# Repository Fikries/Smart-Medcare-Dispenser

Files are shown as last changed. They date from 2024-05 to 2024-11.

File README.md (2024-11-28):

## Project Name
PERSONAL MEDICINE DISPENSER WITH NOTIFICATION FOR ELDERLY CARE IN NURSING HOME USING ESP32 INTERGRATED WITH MYSQL DATABASE

## Component
- 1.Esp32 Devkit v1
- 2.push buttuon
- 3.Led
- 4.Stepper motor 28-byj
- 5.Uln2003
- 6.adapter 12V
- 7.LCD 16 X 2
- 8.BUZZER

## HOW TO SET UP MY PROJECT
- 1.Pull all the code to Vs code
- 2.download Xampp
- 3.make sure on xampp,press start apache
- 4.press admin on xampp control panel
- 5.build one table name and and import table MYSQL from the github
- 6.press admin on apache at xampp control panel
- 7.make sure directary like this "http://localhost/fikrifyp/login.php" it depend on what you save code folder on your laptop
- 
- 8.Because of this project rely on changes of ip address because of using hotspot phone, there are 2 way to find it and one from serial monitor arduiono ide and one from phone
- WhatsApp Image 2024-11-26 at 21 02 38_f4ae71a4
- WhatsApp Image 2024-11-26 at 21 02 38_19f7a604
- 9.After you got ip address, make sure change the ip address on interface.php and spinworker.php

## how to set up PHPMAILER
- 1.OPEN GOOGLE ACC
- 2.PRESS MANAGE ACC
- 3.SEARCH APP PASWORD
- 4.CONFIGURE UNTUILL YOU GET THE CODE THEN PASTE IT INTO THE CODING
- 
- 5.paste it into mail password
- 

- whoever want detail of my fyp can contact me through 0182671172

## Project picture
- WhatsApp Image 2024-10-29 at 00 03 51_c078c0ca

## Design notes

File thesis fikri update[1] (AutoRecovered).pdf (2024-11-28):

## SMART MEDCARE DISPENSER: PERSONAL

## MEDICINE DISPENSER WITH NOTIFICATION

## FOR ELDERLY CARE IN NURSING

## HOME USING ESP32 INTEGRATED

## WITH MYSQL DATABASE

MUHAMMAD FIKRI BIN ZAHARUDIN

MARA JAPAN INDUSTRIAL INSTITUTE

DECLARATION OF THESIS /PROJECT REPORT AND COPYRIGHT

Author’s full name | Date of Birth
MUHAMMAD FIKRI BIN ZAHARUDIN | 26 FEBRUARY 2002
Title | : SMART MEDCARE DISPENSER: PERSONAL MEDICINE DISPENSER WITH
NOTIFICATION FOR ELDERLY CARE IN NURSING HOME USING ESP32 INTERGRATED WITH MYSQL DATABASE

Academic Session : 2022 -2024

I declare that this project report is classified as:

CONFIDENTIAL (Contains confidential information under the Official Secret Act 1972)*

RESTRICTED | (Contains restricted information as specified by the
organization where research was done)*

✓

OPEN ACCESS I agree that my project report to be published as online open access (full text)

I acknowledged that MARA Japan Industrial Institute reserves the right as follows:
1. The project report is the property of MARA Japan Industrial Institute
2. The Library of MARA Japan Industrial Institute has the right to make copies for the purpose of research only.
3. The Library has the right to make copies of the project report for academic exchange.

Certified by:

SIGNATURE | SIGNATURE OF SUPERVISOR
020226-14-1497 | PN AZLIN BINTI RAMLI
(NEW IC NO/PASSPORT) | (NAME OF SUPERVISOR)
Date: 05 December 2024 | Date: 05 December 2024

MJII LIBRARY 2017

NOTES: | * | If the thesis is CONFIDENTAL or RESTRICTED, please attach with the letter from the organization with period and reasons for confidentiality or restriction.

MARA JAPAN INDUSTRIAL INSTITUTE

## MARA JAPAN INDUSTRIAL INSTITUTE

PERSONAL MEDICINE DISPENSER WITH NOTIFICATION

FOR ELDERLY CARE IN NURSING USING ESP32

INTEGRATED WITH MYSQL DATABASE

This report submitted in accordance with the

requirements of the MARA Japan Industrial Institute for the

Diploma In Electronics Engineering (Measurement & Control)

by

MUHAMMAD FIKRI BIN ZAHARUDIN

DEPARTMENT OF ELECTRONICS DATA TRANSMISSION & NETWORK

2024

“I hereby declare that we have read this project report and in my

opinion this project report is sufficient in terms of scope and quality for the

award of the Diploma of Electronics Engineering (Measurement & Control)

Signature: | |
Name of Supervisor : | PN AZLIN BIN RAMLI

Date: 5 December 2024

ii

DECLARATION

We hereby declare that this project report entitled “PERSONAL

MEDICINE DISPENSER WITH NOTIFICATION FOR ELDERLY

CARE IN NURSING HOME USING ESP32 INTERGRATED WITH

MYSQL DATABASE” is the result of our own research except as cited in

the references. The project report has not been accepted for any diploma

and is not concurrently submitted in candidature for any other diploma.

Student | : | |
| | (MUHAMMAD FIKRI BIN ZAHARUDIN
Supervisor | : | PN AZLIN BINTI RAMLI
Date | : | 5 DECEMBER 2024

iii

DEDICATION

This thesis is dedicated to my family, whose love, patience, and belief

in me have been the foundation of my journey. To my parents, thank you for

your endless sacrifices, for always standing beside me, and for showing me

what it means to work hard and dream big. Your faith in me has been my

guiding light through even the darkest moments.

And finally, to myself—I thank you for not giving up. For all the late

nights, the doubts, and the struggles, you found the strength to carry on.

This achievement is not just a milestone; it is a testament to resilience,

courage, and the belief that anything is possible with heart and

determination.

ACKNOWLEDGEMENTS

In preparing this thesis, we were in contact with many people,

researchers, academicians, and practitioners. They have contributed towards

my understanding and thoughts. We wish to express our sincere appreciation

to our main thesis supervisor, Mrs. Azlin bin Ramli for encouragement,

guidance, critics and friendship. We are also very thankful to our Head of

Department of Mdm Ts Mohd Khairrul Adzhar Bin Umar for his guidance,

advice and motivation. Without their continued support and interest, this thesis

would not have been the same as presented here.

A special thanks goes to our friends, who have been companions

throughout this journey, sharing in the highs and lows and reminding me that I

am not alone. Their encouragement, humour, and unwavering support have

been a great source of strength, and I am incredibly grateful for their presence

every step of the way.

We are also indebted to MARA Japan Industrial Institute for funding my

Diploma study in terms of fees, monthly allowance and some contribution to

our project expenses. Our fellow Diploma students should also be recognized

for their support. Our sincere appreciation also extends to all our colleagues

and others who have provided assistance on various occasions. Their views

and tips are useful indeed. Unfortunately, it is not possible to list all of them in

this limited space. We are grateful to all our family members.

ABSTRACT

Smart Medcare Dispenser is a device used to monitor the medication times of

the elderly in nursing homes. It is equipped with safety features that use email

notifications designed to inform caregivers on duty that the elderly need to take

their medication at the scheduled times.

Additionally, administrators in the nursing home will input information on a

website to send commands to an ESP32 with WiFi connectivity, which is

installed along with a stepper motor to rotate a container with 4 medication

storage compartments for up to 32 hours. The mechanism used to notify the

elderly includes sound and light. When the elderly hear the sound or see the

light on the device, it will inform them to take their medication according to the

schedule.

After taking their medication, the elderly need to press a switch provided

manually to send data to a MySQL database to store information about the

date, time, and type of medication taken. In this way, the elderly in nursing

homes who need to take medication do not need to worry about taking their

medication or issues with medication management. This system ensures they

receive their medication on time and facilitates caregivers and administrators

in monitoring and managing medication intake more effectively.

ABSTRACT

Smart Medcare Dispenser ialah sebuah alat yang digunakan untuk memantau

masa pengambilan ubat oleh orang tua di rumah orang tua. Ia dilengkapi

dengan ciri-ciri keselamatan menggunakan notifikasi e-mel yang direka khas

untuk memberitahu penjaga yang sedang bertugas bahawa orang tua akan

mengambil ubat pada masa yang ditetapkan mengikut jadual.

Selain itu, pentadbir di rumah orang tua akan mengisi informasi di laman

sesawang bertujuan untuk memberi arahan kepada ESP32 yang dilengkapi

sambungan WIFI dipasang bersama stepper motor untuk memusingkan bekas

yang mengandungi 4 bahagian penyimpanan ubat selama 32 jam. Mekanisma

yang digunakan untuk menginformasikan orang tua melalui bunyi dan cahaya.

Apabila orang tua mendengar bunyi atau melihat cahaya di alat yang

disediakan, ia akan menginformasikan orang tua untuk mengambil ubat

mengikut jadual yang ditetapkan.

Selepas orang tua mengambil ubat, beliau perlu menekan suis yang

disediakan secara manual untuk menghantar data ke pangkalan data MySQL

untuk menyimpan data tentang tarikh, masa, dan jenis ubat yang diambil.

Dengan cara ini, orang tua di rumah orang tua yang perlu mengambil ubat

tidak perlu risau tentang pengambilan ubat dan kes-kes pengaturan ubat di

rumah orang tua. Sistem ini memastikan mereka mendapat ubat pada masa

yang ditetapkan, dan memudahkan penjaga serta pentadbir untuk memantau

dan menguruskan pengambilan ubat dengan lebih berkesan.

vii

TABLE OF CONTENTS

CHAPTER | TITLE | PAGE
DECLARATION | ii
DEDICATION | iii
ACKNOWLEDGEMENTS | 4
ABSTRACT | 5
ABSTRACT | 6
TABLE OF CONTENTS | vii
LIST OF TABLES | x
LIST OF FIGURES | xi
LIST OF ABBREVIATIONS | xiv
LIST OF SYMBOLS | xv
LIST OF APPENDICES | xvi
1 | INTRODUCTION | 1
1.1 | Background of Research | 1
1.1.1 Example of elder get medication error | 4
1.2 | Problem Statement | 5
1.3 | Project Aim & Objectives | 7
1.4 | Scopes | 8
2 | LITERATURE REVIEW | 10
2.1 | Related Previous Projects | 11
2.1.1 Using Pen And Paper | 12
2.1.2 Medication Management Using Arduino Uno | 13

2.1.3 Automatic Medicine Reminder Using Arduino

Nano | 15
3 | MATERIALS AND METHOD | 17
3.1 | Project Development | 17
3.2 | Components Used / Requirement | 19

viii

3.2.1 Esp32 Devkit V1 | 20
3.2.2 Liquid Crystal Display LCD 16x2 With I2C | 24
3.2.3 Light Emitting Diode (Led) | 25
3.2.4 28Byj-48 5v Stepper Motor | 27
3.2.5 ULN 2003 Driver Motor | 29
3.2.6 Wires Jumper | 30
3.2.7 Buzzer | 31
3.2.8 Push Button | 32
3.2.9 Dc Adapter 12V | 33
3.2.10 PCB Board | 34
3.2.11 : 3d Printed Model | 35
3.3 | Block Diagram | 36
3.4 | Project Flowchart | 38
3.6 | Costing | 40
3.6.1 Miscellaneous Costing | 41
3.6.2 Project Costing | 42
3.7 | Arduino Ide | 43
3.8 | Easyeda | 44
3.9 | Visual Studio Code | 46
3.10 Onshape | 48
3.11 Mysql Database | 49
4 | RESULTS AND DISCUSSION | 50
4.1 | Overall System Performance | 52
4.1.1 Software Implementation | 52
4.1.2 Hardware Implementation | 52

4.1.3 Final Design and Operational Demonstrations 53

4.2 | View Of 3d Design | 63
4.3 | Simulation | 65
4.4 | Circuit Measurement | 66
4.5 | PCB Design | 70
5 | CONCLUSION AND RECOMMENDATIONS | 72
5.1 | Conclusion | 73
5.2 | Future Developments | 74

ix

REFERENCES | 75

x

LIST OF TABLES

TABLE NO | TITLE | PAGE
Table 2.1: | Previous Projects / Literatures | 11
Table 3.1: | Requirement Component for Personal Medicine | 19
Table 3.2 | Connection Esp32 | 21
Table 3.3: | miscellaneous Costing | 41
Table 3.4: | Total Project Costing | 42

xi

LIST OF FIGURES

FIGURE NO | TITLE | PAGE
Figure 1.1: | Observation at Pusat Jagaan Mahmudah | 2
Figure 1.2: | Data from www.nursinghomeabuse.org | 4
Figure 1.3: | Current Intake Database | 5
Figure 1.4 | Lack of medicine arrangement | 6
Figure 2.1: | Nursing home record data using pen and paper | 12
Figure 2.2: | Front Page of the Training Module | 13
Figure 2.3 | Meduino | 15
Figure 3.1: | Esp32 Devkit V1 | 20
Figure 3.2: | Liquid Crystal Display LCD 16x2 With I2c | 24
Figure 3.3: | Led | 25
Figure 3.4: | Stepper Motor | 27
Figure 3.5: | ULN 2003 Driver Motor | 29
Figure 3.6: | Wires Jumper | 30
Figure 3.7: | Buzzer | 31
Figure 3.8: | Push Button | 32
Figure 3.9: | Dc Adapter 12V | 33
Figure 3.10: PCB Board | 34
Figure 3.11:3d Printed Model | 35
Figure 3.12: Block Diagram | 36
Figure 3.13 Product Diagram | 37
Figure 3.14: Flowchart | 38
Figure 3.15 Arduino Ide | 43
Figure 3.16 Easyeda | 44

xii

Figure 3.17 Vs Code | 46
Figure 3.18 Onshape | 48
Figure 3.19 Mysql | 49
Figure 4.1: | Final Project Design | 53
Figure 4.2: | Login Page | 54
Figure 4.3: | Administrator Must register elder’s | 54
Figure 4.4: | Administrator pages | 55
Figure 4.5: | Administrator need to press the “Test Spin” Button | 55
Figure 4.6 | If Administrator has done press the “Test Spin”
| Button, Server has send data to Esp32 | 56
Figure 4.7 | The ESP32 has already received the data string from
| the web application, and the stepper motor will rotate
| 90 degrees, causing the buzzer and LED to High | 56
Figure 4.8 | If someone triggers the push button, the LCD display
| will display “thank you”, followed by the current time. | 57
Figure 4.9 | Before submitting the form, the administrator must fill
| up the elder's details in the admin pages. | 57

Figure 4.10 After administrator submit the form, Server will
| request to Esp32 | 58

Figure 4.11 Administrator need to press “Start Spin Worker” at Figure 4.7 so that Web application can send data
| every 3 second. | 58

Figure 4.12 After ESP32 received data string from the web
| application, Stepper motor will rotate based on
| schedule and other component will work like Figure
| 4.7-4.8 | 59

Figure 4.13 Administrator can check the status to see if the elder
| has taken the medication yet. If the status has
| showed Green, then means Elder has taken the
| medicine. | 59
Figure 4.14 Table for Admin detail | 60
Figure 4.15 Table for register | 60
Figure 4.16 Table for monitoring | 61
Figure 4.17 Notification Status Using Gmail | 62
Figure 4.18 Top View | 63

xiii

Figure 4.19 Left View | 63
Figure 4.20 Right View | 64
Figure 4.21 Back View | 64
Figure 4.22 Simulation | 65
Figure 4.23 Voltage at Power Jack | 66
Figure 4.24 Voltage at Capacitor1 | 66
Figure 4.25 Voltage at Regulator | 67
Figure 4.26 Voltage at Capacitor2 | 67
Figure 4.27 Voltage at at Stepper motor | 68
Figure 4.28 Voltage during rotation at stepper motor | 68
Figure 4.29 Voltage at Buzzer and Led during High | 69
Figure 4.30 Voltage at Push Button During Pressed | 69
Figure 4.31 Back Design for PCB board | 70
Figure 4.32 Top Design for PCD Board | 70

xiv

LIST OF ABBREVIATIONS

mAh | - | milliampere-hour
USB | - | Universal Serial Bus
IoT | - | Internet of Things
Wi-Fi | - | Wireless Fidelity
LED | - | Light Emitting Diode
DC | - | Direct Current
kHz | - | kilohertz
API | - | Application Programming Interface
SMS | - | Short Message Service
FYP | - | Final Year Project
VCC | - | Voltage Common Collector
VIN | - | Voltage Input
GND | - | Ground
GPIO | - | General Purpose Input/Output
PVC | - | polyvinyl chloride
LAN | - | Local Area Network
R&D | - | Research & Development

xv

LIST OF SYMBOLS

xvi

LIST OF APPENDICES

APPENDIX | TITLE | PAGE
APPENDIX A | ARDUINO IDE CODING | 76
APPENDIX B | GANTT CHART | 83

## CHAPTER 1

1INTRODUCTION

### 1.1 Background of Research

Based on research and observations of nursing homes in Bangi which

is Pusat Jagaan Mahmudah, it has been discovered that these facilities face

issues with medicine arrangement and a lack of proper databases. These

challenges often result in medication errors that may surprise elderly residents

and compromise their health and safety. Additionally, the traditional method of

data collection, which relies on pen and paper, further exacerbates the

problem by being inefficient and prone to errors.

To address these challenges, a proposal has been developed for a

"Personal Medicine Dispenser with Notification for Elderly Care in Nursing

Homes Using ESP32 Integrated with MySQL Database". This system is

designed to resolve the current difficulties faced by nursing homes, streamline

medication management, and provide real-time database updates to improve

the overall experience for the elderly.

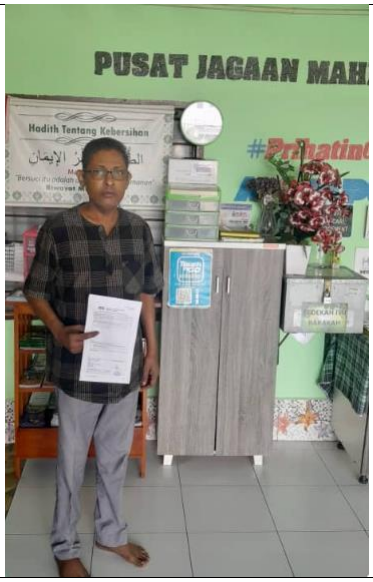
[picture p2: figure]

Figure 1.1: Observation at Pusat Jagaan Mahmudah

Pusat Jagaan Mahmudah is a well-known nursing home in Malaysia

dedicated to providing care and assistance to the elderly. It serves as a safe

haven for individuals who require specialized care due to aging, health

conditions, or lack of familial support. The center focuses on enhancing the

quality of life for its residents by addressing their physical, emotional, and

medical needs in a compassionate environment. However, like many other

nursing homes in Malaysia, Pusat Jagaan Mahmudah faces challenges in

managing medication intake for its residents effectively.

One of the significant issues in elderly care, as observed in Pusat

Jagaan Mahmudah, revolves around medication errors and inefficient record-

keeping systems. Traditional methods, such as manual data entry using pen

and paper, increase the likelihood of errors, delays, and mismanagement.

Such practices can lead to severe consequences, including health deterioration among residents due to missed or incorrect dosages of medicine.

These challenges underscore the need for modern, technology-driven

solutions to ensure safety and efficiency in medication management.

The proposed "Personal Medicine Dispenser with Notification for

Elderly Care in Nursing Homes Using ESP32 Integrated with MySQL

Database" directly addresses these issues. This system automates medicine

dispensing and integrates a digital database to record and monitor medication

schedules in real time. For nursing homes like Pusat Jagaan Mahmudah, this

solution offers a way to transition from traditional, error-prone systems to a

streamlined, reliable approach. The integration of IoT and database

technology ensures that caregivers have access to accurate, up-to-date

information, reducing the chances of medication errors and improving the

overall standard of care.

In addition, the project aligns with the goals of Pusat Jagaan Mahmudah

by promoting resident safety, enhancing the efficiency of caregivers, and

supporting the center’s mission to provide quality elderly care. By

implementing such technology, nursing homes can better meet the needs of

their residents while fostering trust among families who rely on these facilities

to care for their loved ones. This project represents a crucial step toward

modernizing elderly care in Malaysia and ensuring a safer, healthier

environment for the elderly.

### 1.1.1 Example of elder get medication error

Figure 1.2: Data from www.nursinghomeabuse.org

Medication errors in nursing homes are a significant issue, with an

estimated 7,000 to 9,000 deaths annually in the United States due to such

errors and countless others suffering adverse reactions or complications.

According to NursingHome.org, common errors include administering the

wrong medication, incorrect dosages, or failing to ensure medication intake,

often stemming from understaffing, lack of training, or communication gaps.

These preventable mistakes result in life-threatening situations, wrongful

deaths, and billions in healthcare costs. Addressing medication errors is crucial

to safeguarding nursing home residents, particularly the elderly, who are more

vulnerable to these events.

### 1.2 Problem Statement

Nursing homes face significant challenges in the arrangement and

management of medication for their elderly residents. One of the primary

issues is the lack of an efficient database system. Currently, nursing homes

rely on traditional methods, such as paper and pen, to record medication

intake. This outdated system is prone to errors, including misinterpretation of

handwriting, misplaced records, and difficulties in tracking and retrieving

information.

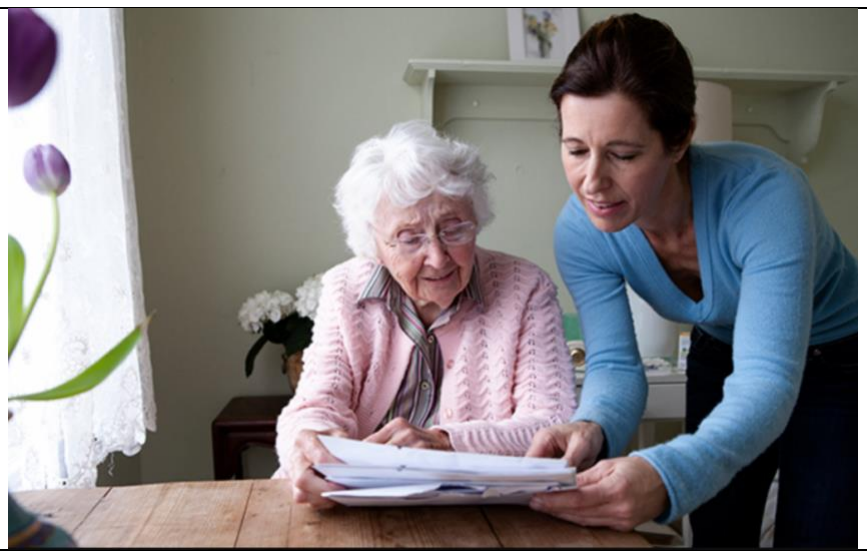
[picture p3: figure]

Figure 1.3: Current Intake Database

The lack of a digital database also complicates the monitoring and

reporting processes. Administrators and caregivers have difficulty in

generating accurate and timely reports on medication compliance, which are

essential for medical reviews and audits. This situation highlights the urgent

need for a modern, automated system to streamline medication management

and improve the accuracy and accessibility of medication records in nursing

homes.

Figure 1.4 | Lack of medicine arrangement
Furthermore, | managing | medication | schedules | manually | is

cumbersome and increases the risk of missed or incorrect doses. Caregivers

often struggle to ensure that each resident receives their medication at the

correct times, especially when handling multiple residents with different

medication needs. This inefficiency can lead to serious health risks for the

elderly, such as adverse drug reactions or deterioration of health conditions

due to missed doses.

### 1.3 Project Aim & Objectives

The aim of this project is to develop a prototype of a pillbox that notifies

the elderly to take their medications and integrates a web application to

facilitate seamless communication for caregivers regarding prescriptions. This

project seeks to improve medication management in nursing homes by

providing a reliable notification system and an efficient platform to enhance

caregiving efficiency and ensure the health and safety of elderly residents.

This objective focuses on developing a smart pillbox with an automated

dispenser integrated with a web application to ensure accurate and timely

medication dispensing for elderly users. The dispenser will be controlled by a

microcontroller, | enabling real-time | monitoring and | management | of

prescriptions. The web application will allow caregivers to efficiently input and

update medication schedules, providing reliable data and notifications to

ensure adherence. This system aims to enhance medication management and

improve the quality of care for elderly residents in nursing homes.

The second objective is to implement a notification system that alerts

elderly residents to take their prescribed medication on time. This system will

utilize a buzzer and LED as reminders, activated according to a predefined

schedule. By ensuring timely notifications, the system aims to support

adherence to medication routines, addressing challenges faced by elderly

individuals in managing their prescriptions effectively.

### 1.4 Scopes

The proposed medicine dispenser is designed to target elderly

individuals who require regular intake of medication pills and caregivers, such

as nurses, who manage the care of older patients. By addressing the

challenges faced by this demographic, the dispenser aims to simplify the

medication management process, ensuring that users adhere to their

prescribed schedules efficiently and reliably. This solution is particularly

beneficial in nursing homes, where caregivers oversee multiple patients and

require effective tools to ensure medication adherence.

The medicine box is programmable, allowing caregivers to customize it

based on individual patient needs. It includes four partitions, each capable of

accommodating medication schedules for up to eight hours. Caregivers can

specify the pill quantity for each partition through a user-friendly web

application. This level of programmability enhances the dispenser's versatility,

making it suitable for diverse medical routines and ensuring that the system is

adaptable to varying prescription requirements.

To ensure adherence to medication schedules, the medicine dispenser

employs a combination of sound and light notifications to remind elderly users

when it is time to take their medicine. These reminders are automated and

triggered according to the schedule set by the caregiver through the web

application. By integrating sound and light alerts, the dispenser ensures that

the reminders are effective and accessible, even for users with hearing or

visual impairments. This comprehensive approach improves the overall

efficiency of medication management and supports caregivers in providing

better care.

Additionally, the current alert system's reliance on siren functionality

presents another constraint. The siren, which emits only a flashing red light

without accompanying sound, limits its effectiveness in notifying residents over

longer distances or in noisy environments. This visual-only alert system may

be inadequate during nighttime or adverse weather conditions when visibility

is reduced. Enhancing the alert system to include audible alarms alongside

visual cues would improve its overall reliability and ensure timely evacuation

notifications during emergencies.

## CHAPTER 2

2LITERATURE REVIEW

A description of the existing approaches available or being developed

to solve the challenges or concerns raised in the project is provided in the

literature review chapter. Understanding and explaining past researchers'

work, including their methodology, theories, and approaches to problem-

solving, as well as the accompanying benefits and drawbacks, difficulties, and

challenges, is crucial. For instance, the gadgets already available on the

market that are utilized to address the difficulties or issues covered in the

project should be highlighted in this chapter. This chapter can build a

knowledgeable awareness of the present market environment by focusing on

the distinctive characteristics or advantages of these gadgets over competing

models. Additionally, by highlighting the technological developments that led

to the widespread use of these gadgets, this chapter might encourage students

to experiment with and develop new uses for this technology. This may result

in a greater comprehension of the skills and procedures needed to produce

innovation.

### 2.1 Related Previous Projects

Table 2.1: | Previous Projects / Literatures
Author | Year | Purpose / Objective | Weakness
PUSAT JAGAAN MAHMUDAH Lot 495/5 Kampung Sungai Purun 43500 Semenyih Selangor | 2012 | Using Pen And Paper | Human Error Don’t Have Database
Bilal, M. (2023) Automatic pill dispenser: Arduino-powered medication management, Use Arduino for Projects. Available at: https://duino4projects.com/automatic-pill-dispenser/ (Accessed: 24 November 2024). | 2023 | Medication Managemen t Using Arduino Uno | Box material is not food grade Don’t Have Database
MeDuino: Smart Automatic Medicine Reminder. (2018). Arduino Project Hub. https://projecthub.arduino.cc/ashraf_minhaj/meduino-smart-automatic-medicine-reminder-12ffd4 | 2018 | Automatic Medicine Reminder Using Arduino Nano | Only Focus On Reminder and don’t have Database

### 2.1.1 Using Pen And Paper

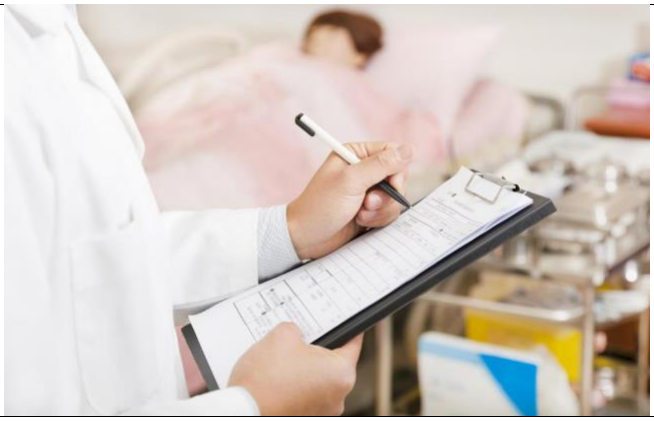
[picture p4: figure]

Figure 2.1: Nursing home record data using pen and paper

At Pusat Jagaan Mahmudah in Bangi, the traditional pen-and-paper

method for managing residents' prescribed medications through the

Medication Administration Record (MAR) is still widely practiced.

Caregivers or nurses manually document vital details such as medication

names, dosages, and administration times on the MAR sheet. Each time

medication is administered, they record the date and time, along with their

initials or signature, to verify the task's completion. While this system ensures

accountability, it is time-consuming and prone to human error, particularly in

environments like Pusat Jagaan Mahmudah, where caregivers manage

multiple residents with varying medication schedules. Modernizing this

process with automated solutions could significantly enhance efficiency and

reduce the risk of errors. After observation, the table has been take note as

method to create the website.

### 2.1.2 Medication Management Using Arduino Uno

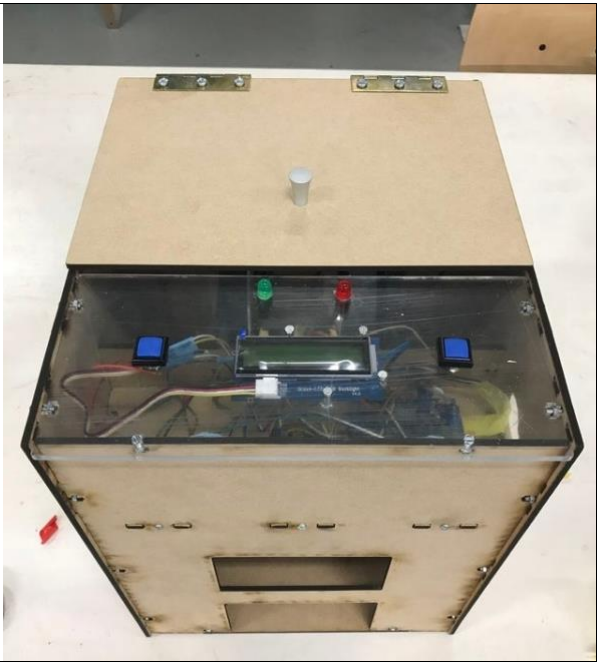
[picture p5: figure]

Figure 2.2: Front Page of the Training Module

This project, originally designed and implemented by Bruface

Mechatronics with group member of Federico ghezzi, Andrea Molino, Giulia

Ietro, Mohammad Fakih and Mouhamad Lakkis for Project Group 2, serves as

a comprehensive guide for developing a pill dispenser robot. The project

provides step-by-step instructions on building and programming the device,

with features such as automated pill dispensing and refill mechanisms,

Bluetooth connectivity, and user interaction through an application. These functionalities are vital for enhancing the efficiency and reliability of medication

management, particularly for elderly patients and caregivers.

The project highlights the advantages of using stepper motors, a Motor

Shield, and a Real-Time Clock (RTC) module to ensure precise and timely pill

dispensing. The integration of humidity and temperature sensors, along with

an LCD display, further improves the usability and reliability of the dispenser.

The use of PIR sensors adds an extra layer of functionality by detecting user

interaction, ensuring that pills are dispensed accurately and received by the

patient. These components are essential for creating an efficient and user-

friendly device.

However, the literature also discusses potential limitations in the system

design, such as the focus on specific hardware components like the Arduino

UNO and Bluetooth modules. This restricted scope may limit the exploration

of alternative or more advanced technological solutions that could further

optimize the dispenser. Addressing these challenges could lead to more robust

designs, ensuring the dispenser meets a wider range of user needs, including

those at facilities like Pusat Jagaan Mahmudah, where medication

management is critical. Based on the evaluation of this project, improvements

were identified, including the use of food-grade materials and the

implementation of a database for the personal medicine dispenser with

notifications for elderly care in nursing homes, utilizing an ESP32 integrated

with a MySQL database.

### 2.1.3 Automatic Medicine Reminder Using Arduino Nano

Figure 2.3 Meduino

The Smart Medcare Dispenser project is designed to create a simple

and affordable medication reminder system using Arduino technology. The

primary goal is to ensure timely medication intake, which is particularly

beneficial for the elderly and individuals with complex medication regimens. By

emitting periodic alarms, the system effectively prompts users to take their

medications on schedule, helping to prevent missed doses and improving

overall health outcomes.

Smart Medcare Dispenser is characterized by its minimalistic design

and customizable settings, which make it user-friendly and flexible. The

straightforward operation of the device ensures that it can be easily used by

individuals with varying levels of technical expertise. The project’s use of low-

cost components and its open-source nature further enhance its accessibility,

allowing a wide range of users to benefit from its functionality.

For caregivers, Smart Medcare Dispenser provides peace of mind by

ensuring that their loved ones adhere to their medication schedules, even

when they cannot be present. This practical solution not only supports better

medication adherence but also contributes to improved health and well-being

for users. From this project take reminder as benchmark to incorporate in this

project

## CHAPTER 3

3MATERIALS AND METHOD

### 3.1 Project Development

The project development for the medicine dispenser system follows a

structured process, spanning 17 weeks in FYP1 and 19 weeks in FYP2,

designed to address medication management challenges for elderly residents

in nursing homes, particularly at Pusat Jagaan Mahmudah. Initially, the project

involved planning and ideation, with a briefing on final year projects and a

discussion of potential topics aimed at community impact. Early tasks included

selecting a project title, identifying key components, and setting project

objectives. Researching medicine dispensing solutions, the team examined

various ESP32 capabilities, including the use of a stepper motor to accurately

dispense pills.

In the following weeks, industry research and panel feedback were

gathered to ensure the project’s relevance and applicability. Key components,

such as the stepper motor, push buttons, and LCD display, were procured, and

caregivers at nursing homes were interviewed to understand real-world needs.

Development then advanced to testing individual components like the stepper

motor and LCD display, followed by integrating the ESP32 microcontroller with the dispenser modules. Circuit and block diagrams were created to visualize

the setup and operational flow, using software tools.

In FYP2, focus shifted to user interface and project refinement.

Continuous testing and system enhancements were conducted to ensure

reliable performance in medication scheduling and dispensing scenarios. A

web application was implemented to allow caregivers to manage prescriptions

remotely, while an alarm system was designed for notifying elderly patients

when it is time to take their medication. Daily testing was carried out leading

up to the final demonstration. This approach underscores the importance of

structured project stages, from initial concept to testing, to achieve an effective

medicine dispenser system for community use.

### 3.2 Components Used / Requirement

During the process of completing the project, some hardware and

software was used to undergo the process. These tools were used and had

their purposes and was compiled together to complete the project.

Table 3.1: Requirement Component for Personal Medicine

Dispenser With Notification For Elderly Care In

| Nursing Home Using Esp32 Integrated With
| Mysql Database
NO | COMPONENT | QUANTITIES
1 | Esp32 Devkit V1 | 1
2 | Liquid Crystal Display LCD 16x2 With I2c | 1
3 | Light Emitting Diode (Led) | 3
4 | 28Byj-48 5v stepper motor | 1
5 | Uln 2003 Driver Motor | 1
6 | Wires Jumper | 8
7 | Buzzer | 1
8 | Push Button | 1
9 | Dc Adapter 12v | 1
10 | Pcb Board | 5
11 | 3D Printed Model | 1

### 3.2.1 Esp32 Devkit V1

Figure 3.1: Esp32 Devkit V1

The ESP32 DevKit V1 is a development board built around the ESP32

microcontroller, known for its integrated Wi-Fi and Bluetooth capabilities. This

makes it an ideal platform for developing IoT and embedded systems projects.

The board features a powerful dual-core processor with a 32-bit architecture,

allowing it to handle complex tasks efficiently. It also comes with multiple GPIO

pins, enabling easy interfacing with various sensors, actuators, and other

peripherals. The built-in antenna simplifies wireless communication,

eliminating the need for external hardware.

One of the key strengths of the ESP32 DevKit V1 is its versatility. It

supports multiple programming environments, including the Arduino IDE,

MicroPython, and Espressif’s own ESP-IDF framework, catering to developers

of different expertise levels. The board provides a wide range of connectivity

options, such as I2C, SPI, UART, and PWM, which facilitate seamless

integration with other devices. With ample onboard flash memory and SRAM,

it is well-suited for projects requiring significant computational resources.

The compact design of the DevKit V1 makes it a great choice for

projects with size constraints. Its easy-to-use layout is compatible with

breadboards, and the integrated USB-to-serial converter simplifies

programming and debugging. With a wide input voltage range (5V to 12V), the

board is adaptable to various power supplies. The ESP32 DevKit V1 continues

to be a popular choice for both hobbyists and professionals in building

connected devices and smart

Table 3.2 | Connection Esp32
No | Pin | Connection
1 | Vcc | Stepper Motor
2 | Gnd
3 | D13
4 | D12
5 | D14 | In1
6 | D27 | In2
7 | D26 | In3
8 | D25 | In4
9 | D33
10 | D32

11 | D35
12 | D34
13 | VN
14 | VP
15 | EN
16 | D23
17 | D22 | SCL Lcd display
18 | TX
19 | RX
20 | D21 | SDA Lcd display
21 | D19 | Led
22 | D18 | Buzzer
23 | D5
24 | TX2
25 | RX2

26 | D4 | Push Button
27 | D2
28 | D15
29 | GND
30 | 3V3 | Push Button

### 3.2.2 Liquid Crystal Display LCD 16x2 With I2C

Figure 3.2: Liquid Crystal Display LCD 16x2 With I2c

The 16x2 Liquid Crystal Display (LCD) with I2C interface is a widely

used module in embedded systems and microcontroller projects, featuring two

rows of 16 characters each, perfect for displaying text, numbers, and simple

symbols. This LCD uses liquid crystal technology, which is energy-efficient and

operates with low power. The backlit screen enhances visibility in various

lighting conditions, making it ideal for applications requiring a clear user

interface, such as home appliances, digital meters, and DIY electronics

projects.

The 16x2 LCD's I2C interface offers significant advantages in terms of

simplicity and ease of use. Unlike standard LCDs that require 6 to 10 GPIO

pins, the I2C version only needs two: one for the clock (SCL) and one for the

data (SDA). This reduces wiring complexity, freeing up more GPIO pins for

other components, and simplifying circuit design, making it accessible for

beginners and efficient for advanced projects.

The LCD is usually paired with a small I2C backpack containing an I2C

expander chip (typically a PCF8574), which converts I2C signals into parallel

signals required by the LCD. The I2C interface also supports multiple devices

on the same bus, enabling complex systems with various I2C components.

Libraries for platforms like Arduino IDE make it easy to control the display,

adjust backlight brightness, and create custom characters, making the 16x2

LCD with I2C a versatile solution for a wide range of electronic projects.

### 3.2.3 Light Emitting Diode (Led)

Figure 3.3: Led

A Light Emitting Diode (LED) is a semiconductor device that emits light

when an electric current passes through it. Unlike traditional incandescent

bulbs, which generate light by heating a filament, LEDs produce light through

electroluminescence. This process involves electrons recombining with holes

in the semiconductor material, releasing energy as photons. LEDs are highly

energy-efficient, producing minimal heat and consuming less power than other

lighting technologies. They come in various colors, such as red, green, blue,

and white, and can be used individually or combined to create multicolor

displays or emit specific wavelengths of light.

LEDs are renowned for their durability and longevity, often lasting tens

of thousands of hours. Their long lifespan and low energy consumption make

them an environmentally friendly and cost-effective lighting option. As solid-

state devices, LEDs are more resistant to shock and vibration than traditional

light sources, making them suitable for harsh environments. Their compact

size offers design flexibility, allowing their use in everything from small

indicator lights to large-scale displays and automotive lighting.

Beyond simple illumination, LEDs have diverse applications in modern

electronics. They are used as indicator lights, in digital displays, and in

communication systems like fiber-optic networks. The precise control of LED

intensity and color has led to their adoption across various industries, including

consumer electronics, automotive, medical devices, and art installations.

Advancements in LED technology continue to drive the development of

energy-efficient and versatile lighting solutions globally.

3.2.4 28Byj-48 5v Stepper Motor

Figure 3.4: Stepper Motor

The 28BYJ-48 5V stepper motor is a popular, cost-effective choice for

hobbyist projects and small automation tasks. Designed for precise control of

angular position, it is ideal for applications requiring accurate movement, such

as in robotics, 3D printers, and CNC machines. As a unipolar stepper motor, it

features four coils that are energized in sequence to rotate the shaft in small,

discrete steps. Operating at 5V, it is compatible with many microcontrollers,

including Arduino and ESP32.

A key feature of the 28BYJ-48 is its internal gearing mechanism, which

enhances torque while reducing speed. With a step angle of 5.625 degrees

and a 64:1 gear reduction ratio, the motor achieves 32 steps per revolution of

the output shaft, requiring 2048 steps for a full rotation. This high step count

enables precise control, making it suitable for applications like camera

positioning or sewing machine needles.

The 28BYJ-48 is typically paired with the ULN2003 driver module,

which simplifies control by interfacing the motor’s four coils with a

microcontroller. This combination is favored for its affordability, ease of use,

and reliability in low-power applications. The 28BYJ-48 and ULN2003 are widely used in DIY and educational projects due to their effective performance

and availability.

### 3.2.5 ULN 2003 Driver Motor

Figure 3.5: ULN 2003 Driver Motor

The ULN2003 driver module is a widely used integrated circuit designed

to control stepper motors, relays, and other high-current loads. It contains

seven high-current Darlington transistor pairs, which allow it to switch high

voltages and currents with ease. The module is often used in conjunction with

stepper motors, such as the 28BYJ-48, to provide the necessary current to

drive the motor’s coils. Its robust design makes it capable of handling currents

up to 500mA per channel, with a total current rating of 2.5A across all channels.

One of the primary features of the ULN2003 driver module is its ability

to interface with low-voltage microcontrollers, such as those found in Arduino

and ESP32 boards. The module is equipped with input pins that connect to the

microcontroller, and output pins that connect to the motor or other loads. When

a signal is sent from the microcontroller, the ULN2003 amplifies the current

and switches it to the load, enabling precise control of high-current

components without risking damage to the microcontroller.

The ULN2003 module typically includes a built-in flyback diode

protection circuit, which safeguards against voltage spikes caused by inductive

loads like motors and relays. This protection ensures the longevity and

reliability of both the module and connected components. Due to its simplicity,

reliability, and ability to handle higher currents, the ULN2003 driver module is

a popular choice in various electronic projects and applications.

### 3.2.6 Wires Jumper

Figure 3.6: Wires Jumper

Jumper wires are essential components in electronics prototyping and

circuit building. These flexible, insulated wires are used to make temporary

connections between different parts of a circuit, allowing for easy

experimentation and modification. They come in various lengths and colors,

which helps in organizing and managing connections on a breadboard or other

circuit board. Jumper wires are especially useful for connecting

microcontrollers, sensors, actuators, and other electronic components during

the design and testing phases of a project.

Jumper wires are typically available in two main types: male-to-male

and female-to-female. Male-to-male wires have connectors on both ends that

can be inserted directly into a breadboard or other pin headers. Female-to-

female wires, on the other hand, have sockets on both ends and are used to

connect pins or headers that are already in place. Some jumper wires also

come in male-to-female configurations, providing additional flexibility in

connecting different types of components or interfaces.

The ease of use and versatility of jumper wires make them an

indispensable tool for hobbyists, engineers, and educators alike. They facilitate

quick and efficient connections without the need for soldering, making them

ideal for prototyping and iterative development. Jumper wires allow for rapid

adjustments and modifications, which is crucial for troubleshooting and refining

electronic designs

### 3.2.7 Buzzer

Figure 3.7: Buzzer

A buzzer is an electronic component used to produce sound or audio

signals in various devices and systems. It operates by converting electrical

energy into acoustic energy, generating sound through vibration or resonance.

Buzzers are commonly used in alarms, notifications, and alerts in electronic

devices, such as household appliances, car systems, and computer hardware.

They come in different types, including piezoelectric buzzers and

electromagnetic buzzers, each offering distinct sound characteristics and

operating principles.

Piezoelectric buzzers use a piezoelectric crystal to generate sound.

When an alternating voltage is applied to the crystal, it vibrates, producing

sound waves. These buzzers are known for their high efficiency, compact size,

and ability to generate a wide range of frequencies. They are often used in

applications where space is limited and clear, sharp sound is needed, such as

in timers, alarm systems, and small electronic devices.

Electromagnetic buzzers, on the other hand, utilize an electromagnet

and a diaphragm to produce sound. When an electric current passes through

the electromagnet, it attracts and releases a diaphragm, creating sound

waves. These buzzers are typically used in applications requiring louder and

more resonant sounds, such as in large alarm systems and industrial

equipment. Both types of buzzers are valued for their reliability and

effectiveness in delivering auditory signals across various applications.

### 3.2.8 Push Button

Figure 3.8: Push Button

A push button is a simple yet essential component in electronic circuits

and devices, used to provide user input or control various functions. It consists

of a mechanical switch that, when pressed, completes an electrical circuit,

allowing current to flow and triggering a specific action or response in the

connected system. Push buttons are commonly found in everyday devices

such as keyboards, remote controls, appliances, and industrial machinery,

where they serve as the primary means for user interaction and command

input.

Push buttons come in various styles and configurations, including

momentary and toggle types. Momentary push buttons, also known as push-

to-make switches, only complete the circuit while being pressed and return to

their default state when released. These are used in applications where a

temporary action or signal is needed, such as in reset functions or short bursts

of input. Toggle push buttons, on the other hand, latch in an "on" or "off"

position after being pressed, suitable for functions that require a persistent

state, like powering a device on or off.

The versatility and simplicity of push buttons make them a popular

choice for user interfaces and control systems. They can be found in a range

of sizes and designs, from small tactile buttons on a circuit board to large,

rugged buttons used in heavy machinery. Their ease of use, reliability, and

adaptability make them a fundamental component in both consumer

electronics and industrial applications.

### 3.2.9 Dc Adapter 12V

Figure 3.9: Dc Adapter 12V

A DC adapter, also known as a power adapter or power supply, is an

essential component used to convert alternating current (AC) from a wall outlet

into a direct current (DC) suitable for powering electronic devices. The 12V DC

adapter is specifically designed to provide a stable 12-volt DC output, which is

commonly required for a wide range of electronic equipment and gadgets,

including routers, LED lighting, and various types of consumer electronics.

The primary function of a 12V DC adapter is to ensure that electronic

devices receive a consistent and reliable power supply. It typically consists of

a transformer that steps down the high voltage AC from the mains to a lower

AC voltage, followed by a rectifier and voltage regulator that convert and

stabilize the output to a precise 12V DC. This process ensures that sensitive

electronics receive the correct voltage, preventing damage and ensuring

proper operation.

DC adapters come in various form factors, including wall-mounted units

and desktop power bricks. They usually feature a connector or plug that fits

the device's power input socket. The versatility and widespread use of 12V DC

adapters make them a crucial component in both residential and commercial

settings, providing a dependable power source for numerous electronic

devices.

### 3.2.10 PCB Board

Figure 3.10: PCB Board

A printed circuit board (PCB) is a fundamental component in modern

electronics, providing the structural and electrical foundation for assembling

electronic components. It consists of a flat board made from insulating

material, typically fiberglass or composite epoxy, with conductive pathways

etched or printed onto its surface. These pathways, made of copper, create

electrical connections between different components mounted on the board.

The PCB serves as the backbone of most electronic devices, from simple

gadgets to complex computers and industrial machinery.

PCBs come in various types, including single-sided, double-sided, and

multi-layered boards. Single-sided PCBs have components and conductive

pathways on one side, while double-sided boards feature layers on both sides.

Multi-layered PCBs contain several layers of conductive material separated by

insulating layers, allowing for more complex and compact designs. These

different types of PCBs cater to varying needs, from basic applications to

advanced, high-density electronics requiring intricate circuit designs and high

performance.

The design and manufacturing of PCBs involve several steps, including

layout design, etching, soldering, and testing. Modern PCB design software

allows engineers to create precise circuit layouts, which are then transferred

to the board through processes such as photolithography and chemical

etching. Once manufactured, PCBs are populated with electronic components

and tested to ensure proper functionality.

3.2.11 : 3d Printed Model

Figure 3.11:3d Printed Model

A 3D-printed model is a physical object created using additive

manufacturing technology, where material is deposited layer by layer to build

up the final shape. The process begins with a digital 3D model, which is

designed using computer-aided design (CAD) software or scanned from an

existing object. This digital model is then sliced into thin cross-sections, which

guide the 3D printer in constructing the object layer by layer. Materials used in

3D printing include various types of plastics, metals, and resins, depending on

the printer and the application.

One of the primary advantages of 3D printing is its ability to produce

complex geometries and customized parts that would be difficult or impossible

to create with traditional manufacturing methods. This technology allows for

rapid prototyping, enabling designers and engineers to quickly test and iterate

on their designs. It also supports the creation of intricate details and custom

features, which is valuable in fields such as medical implants, automotive

parts, and consumer products.

3D-printed models are used in a wide range of applications, from

industrial prototypes and functional parts to artistic sculptures and

personalized items. The flexibility of 3D printing makes it a popular choice for

both small-scale production and one-off customizations. As the technology

advances, it continues to expand its applications, offering new possibilities for

innovation and design across various industries.

### 3.3 Block Diagram

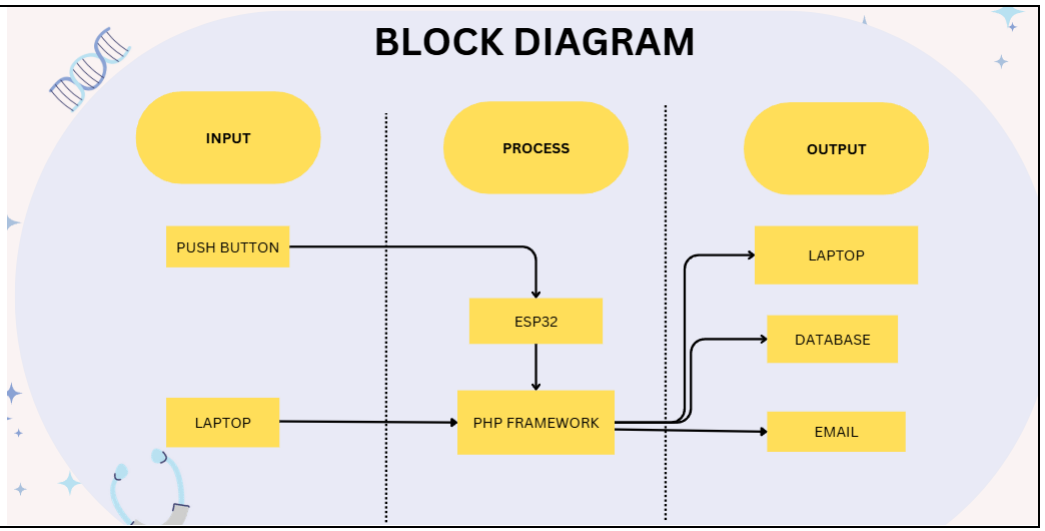
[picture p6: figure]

Figure 3.12: Block Diagram

This block diagram represents the architecture of the medicine

dispenser system designed to ensure efficient and accurate medication

management.

In the Input section, the system receives input through a push button,

which allows manual triggering, and a laptop, which is used to manage and

input data into the system. These inputs serve as the starting point for the

system's operation.

The Process section is powered by the ESP32 microcontroller, which

serves as the core processor. The ESP32 is responsible for handling the input

signals and sending them to the PHP framework for further processing. The

PHP framework manages data storage and communication with other system

components.

In the Output section, processed data is sent to three destinations:

1. Laptop – for displaying real-time information or alerts.
2. Database – for storing medication schedules and records.
3. Email – for sending notifications or alerts to caregivers or users.

This design ensures seamless integration of hardware and software,

allowing for real-time monitoring, manual control, and remote notifications to

enhance the system's usability and reliability

Figure 3.13 Product Diagram

### 3.4 Project Flowchart

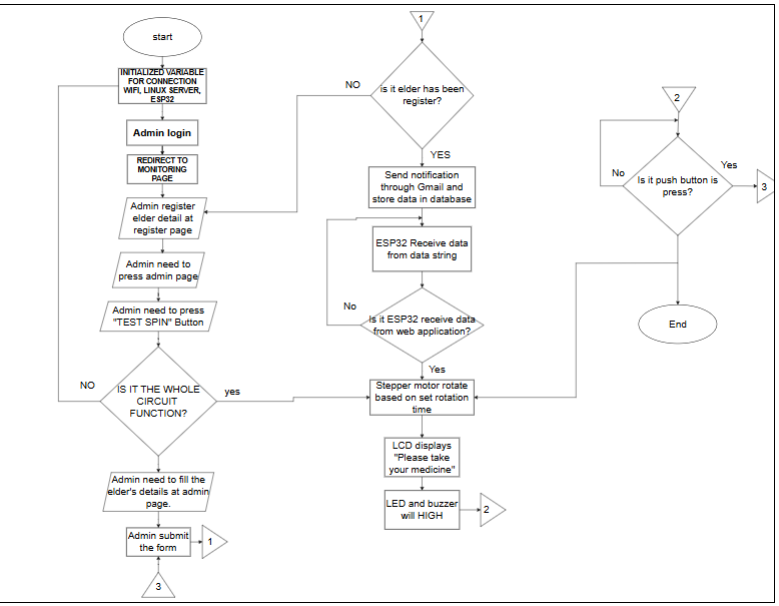
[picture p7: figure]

Figure 3.14: Flowchart

This flowchart represents the operation of a medicine dispenser

system. The process begins with the initialization of variables for connecting

the system to Wi-Fi, a Linux server, and the ESP32 microcontroller. The admin

logs in and is directed to the monitoring page, where they can register an

elder's details. Afterward, the admin presses a "TEST SPIN" button to check

if the system components, such as the stepper motor, LCD, LED, and buzzer,

are functioning correctly.

Once the elder's details are entered and registered, the system sends

a notification to the admin via Gmail and stores the elder's data in a MySQL database. The ESP32 receives the data from the database or from a web

application, triggering the system to perform its tasks. The stepper motor

rotates based on the predefined rotation time, and the LCD displays the

message "Please take your medicine." Additionally, the LED and buzzer are

activated to alert the elder that it is time to take their medicine. The system

ends when the push button is pressed.

### 3.6 Costing

Accurate cost calculations are crucial for project management as they

are the foundation for financial management and decision-making throughout

the pro

ject's lifecycle. They enable project managers to allocate resources

efficiently, track expenses, and ensure the project stays on budget. This helps

in making informed financial decisions and monitoring the project's financial

health. Accurate cost calculations also enable wise spending, budget

adherence, purposeful spending, price comparison, and prudent spending. By

identifying critical elements that require funding and managing them more

economically, project teams can optimize resource allocation and achieve

project objectives without overspending. By conducting price comparisons and

making informed financial decisions based on accurate cost calculations,

project teams can ensure the project's financial stability and success.

### 3.6.1 Miscellaneous Costing

Table 3.3: | miscellaneous Costing
No | Items / Components | Quantity | Cost per unit (RM) | Total Cost
1 | ESP32 Devkit v1 | 2 | 15.00 | 30.00
2 | Push Button | 2 | 4.00 | 8.00
3 | Stepper Motor 28-byj | 2 | 8.50 | 17.00
4 | ULN2003 | 2 | 4.50 | 9.00
5 | LCD 16x2 | 1 | 11.50 | 11.50
6 | Led | 5 | 1.00 | 5.00
7 | Adapter 12V | 1 | 9.00 | 9.00
8 | Wires Jumper | 3 | 8.00 | 24.00
9 | Battery 9V | 1 | 2.30 | 2.30
10 | 3D design model | 2 | 94.00 | 188.00
11 | Breadboard | 1-Set | 9.00 | 9.00
12 | Capacitor | 5 | 0.50 | 2.50
13 | Smd component | 1 | 10.00 | 10.00
14 | Linux server | 1 | 100.00 | 100.00
15 | PCB Board | 5 | 11.00 | 55.00
16 | Payment of Services | 1 | 90.00 | 90.oo
Total | | | | 570.30

### 3.6.2 Project Costing

Table 3.4: | Total Project Costing
No | Items / Components | Quantity | Cost per unit (RM) | Total Cost
1 | ESP32 Devkit v1 | 1 | 15.00 | 15.00
2 | Push Button | 1 | 4.00 | 4.00
3 | Stepper Motor 28-byj | 1 | 8.50 | 8.50
4 | ULN2003 | 1 | 4.50 | 4.50
5 | LCD 16x2 | 1 | 11.50 | 11.50
6 | Led | 2 | 1.00 | 2.00
7 | Adapter 12V | 1 | 9.00 | 9.00
8 | Wires Jumper | 1 | 8.00 | 8.00
9 | Battery 9V | 1 | 2.30 | 2.30
10 | 3D design model | 1 | 94.00 | 94.00
12 | Capacitor | 2 | 0.50 | 1
13 | Smd component | 1 | 10.00 | 10.00
14 | Linux server | 1 | 100.00 | 100.00
15 | PCB Board | 1 | 11.00 | 11.00
Total | | | | 280.80

### 3.7 Arduino Ide

Figure 3.15 Arduino Ide

In this Final Year Project (FYP), the Arduino IDE plays a crucial role in

developing and programming the embedded system. It provides a platform for

writing and uploading code to the Arduino-based microcontroller used in the

project. Its user-friendly interface and wide range of libraries enable efficient

prototyping and integration of hardware components, such as sensors,

motors, and displays, essential for the functionality of the project. The Arduino

IDE's compatibility with the project's hardware ensures smooth communication

and control, making it an ideal tool for implementing the IoT features and

automation required in this FYP.

### 3.8 Easyeda

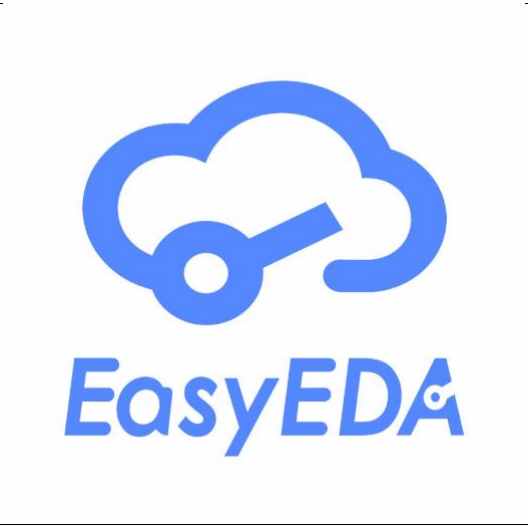
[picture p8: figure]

Figure 3.16 Easyeda

EasyEDA is an essential tool for designing printed circuit boards (PCBs)

in this Final Year Project (FYP). It offers an intuitive, web-based interface for

creating and simulating schematic circuits and laying out PCBs. EasyEDA

simplifies the process of integrating components like microcontrollers,

sensors, and actuators into a compact and reliable PCB design, ensuring the

project's hardware is organized and efficient. Its library of components and

ability to generate manufacturing files, such as Gerber files, make it ideal for

producing custom PCBs tailored to the project's requirements. By using

EasyEDA, the FYP achieves a professional and scalable hardware solution

that enhances reliability and performance.

### 3.9 Visual Studio Code

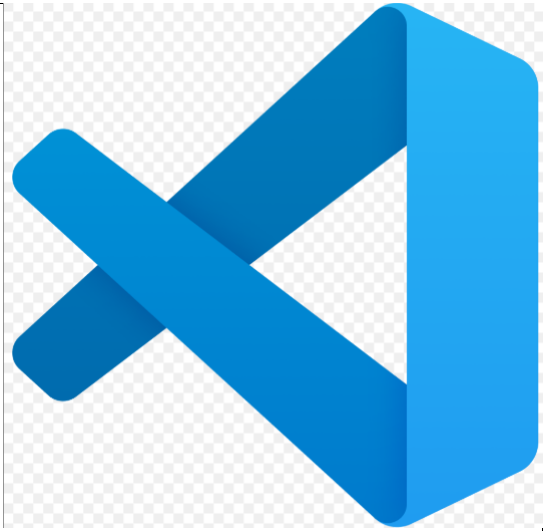
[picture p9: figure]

Figure 3.17 Vs Code

Visual Studio Code (VS Code) is a powerful and versatile code editor

that can significantly enhance the development process for this Final Year

Project (FYP). With its extensive support for various programming languages

and customizable extensions, such as PlatformIO, VS Code enables seamless

programming and debugging of microcontrollers like the ESP32 or Arduino boards. Its features, including intelligent code completion, syntax highlighting,

and integrated version control, streamline the coding workflow. VS Code's

adaptability and efficiency make it an excellent choice for managing complex

FYP tasks, such as implementing IoT functionalities or integrating advanced

software logic, ensuring the project's software development is both efficient

and professional.

### 3.10 Onshape

Figure 3.18 Onshape

Onshape is a cloud-based computer-aided design (CAD) platform used

for creating 3D models and collaborative design work. It provides a robust set

of tools for sketching, parametric modeling, and assembly creation, enabling

precise and efficient 3D design workflows. In this Final Year Project (FYP),

Onshape was utilized to design the 3D prototype of the medicine dispenser,

ensuring that the dimensions and structure met the project's requirements. Its

cloud-based features allowed for easy access, version control, and

collaboration, making it an ideal tool for developing and refining the

dispenser's design for 3D printing and practical implementation.

### 3.11 Mysql Database

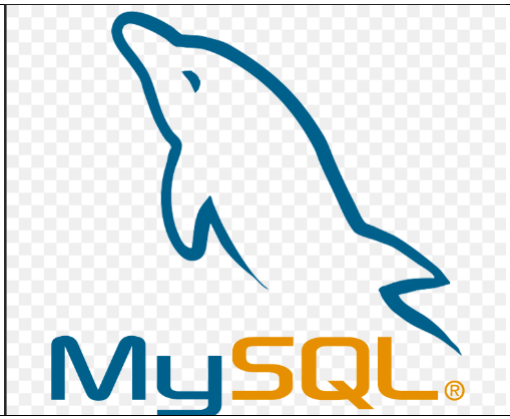
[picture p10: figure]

Figure 3.19 Mysql

MySQL is an open-source relational database management system

(RDBMS) widely used for storing and managing structured data efficiently. In

this Final Year Project (FYP), MySQL is integrated to handle the database for

the medicine dispenser, storing critical information such as medication

schedules, patient details, and notification logs. Its reliability, scalability, and

compatibility with ESP32 and web applications make it ideal for ensuring

seamless data management and retrieval. By utilizing MySQL, the project

achieves a robust backend system that supports real-time updates and secure

data storage, enhancing the overall functionality and user experience of the

dispenser system.

## CHAPTER 4

4RESULTS AND DISCUSSION

Throughout the development of this project, several challenges and

issues were encountered. The initial concept for the medicine dispenser was

designed for elderly individuals in nursing homes, with the goal of creating a

system that could notify them when to take their medications. It also aimed to

integrate a web application that would allow caregivers to easily communicate

and manage prescriptions. Initially, the project considered using a web

application operated on a Linux server for this purpose. However, after

discussions with my supervisor, it was deemed that this approach was efficient

and also I opted for a simpler manual mechanism using a push button, which

the elderly could press after taking their medication, sending the data to a

MySQL database.

Another challenge was selecting the appropriate microcontroller

for the project. Initially, I chose the ESP32 DevKit V1 for its adequate number

of I/O pins to support multiple components, as well as its cost-effectiveness,

which was suitable for the project. Additionally, the project involved configuring

a Wi-Fi connection to store item information in the database. However, using

a hotspot for the ESP32's Wi-Fi connection introduced the problem of

changing IP addresses, which affected the system's ability to communicate

consistently. To address this issue, I had to manually press the reset button each time the circuit was configured to ensure that the IP address remained

stable, preventing interruptions in the system’s operation.

### 4.1 Overall System Performance

### 4.1.1 Software Implementation

This project's software worked completely, finishing the circuit

schematic diagram and programming the project code in quickly time. The

software utilised was important to the project's operation, therefore its success

depended on its ability to function.

### 4.1.2 Hardware Implementation

In this section, a more detailed examination of earlier research findings'

shortcomings is conducted and discussed. The functionality of the project

aligns with the initial predictions, which are ESP32 successfully receives data

string from the web-application, matches the input coding in the microcontroller

at Arduino IDE and Visual Studio Code, and produces the intended output.

This output includes the medicine dispenser’s ability to dispense the medicine

based on administrator set, edits or delete in web-application.

### 4.1.3 Final Design and Operational Demonstrations

### 4.1.3.1 Final Project Design

Figure 4.1: Final Project Design

The “Personal Medicine Dispenser With Notification For Elderly Care In

Nursing Home Using Esp32 Integrated With Mysql Database” has been

successfully developed and working effectively. Figure 4.3 is the final design

for this project. This project can dispense the medicine based on schedule that

administrator has been set in web application. Not only dispense the medicine,

ESP32 also can send data to database such as time and date after elder

press the push button manually. This project also come with features Mysql

database before and after medicine has been taken.

### 4.1.3.2 Smart Medcare System Flow

For the first step administrator need to do is access the login pages and

register the elder detail. It is means that database need to record the detail

before execute.

Figure 4.2: Login Page

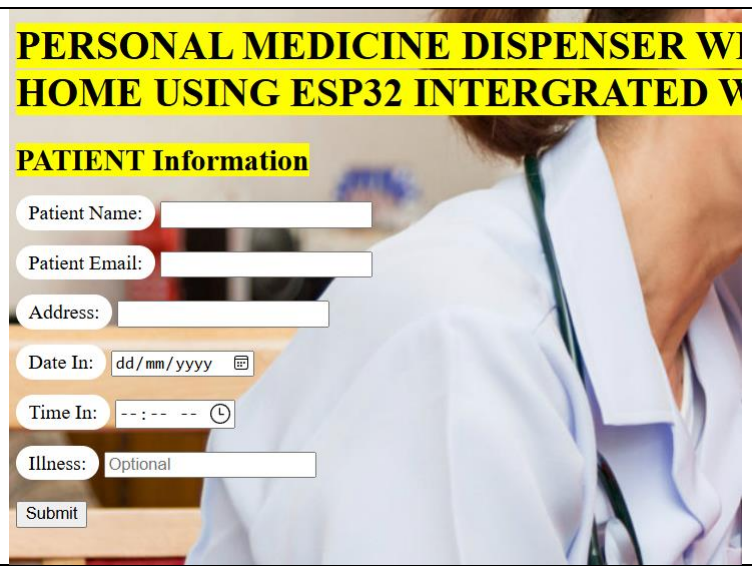
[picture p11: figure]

Figure 4.3: Administrator Must register elder’s

The second step requires the administrator to get through to the login

admin pages and press the "TEST SPIN" button. If the administrator presses

the "TEST SPIN" button, the ESP32 will receive and rotate the stepper motor

90 degrees, the buzzer and led will be high, and if someone presses the push

button, the buzzer and led will be low, and the LCD display will display "thank

you" followed by the current time. If all of the operations follow the flowchart

(Figure), the circuit will run correctly

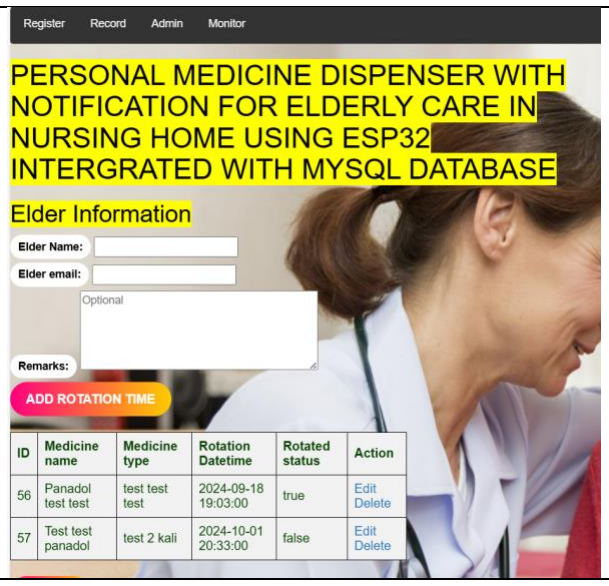
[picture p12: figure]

Figure 4.4: Administrator pages

Figure 4.5: Administrator need to press the “Test Spin” Button

Figure 4.6 | If Administrator has done press the “Test Spin” Button, Server has send data to Esp32

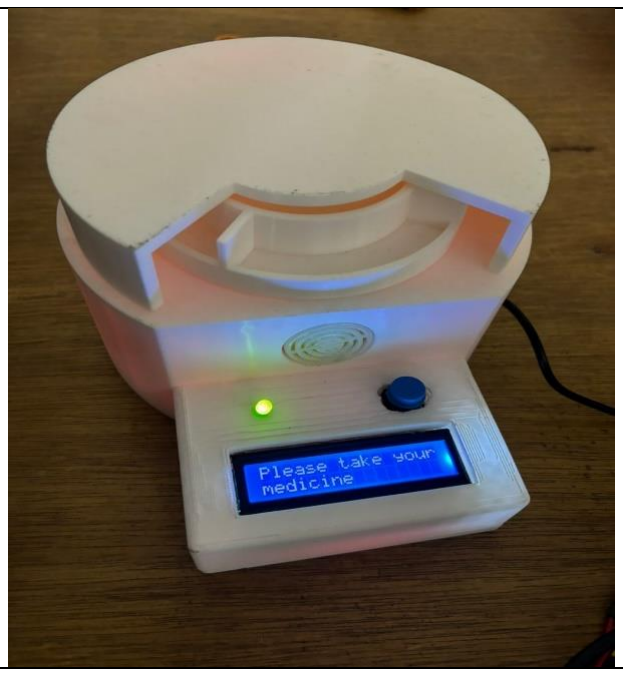
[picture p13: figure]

Figure 4.7 | The ESP32 has already received the data string from the web application, and the stepper motor will rotate 90 degrees, causing the buzzer and LED to High

Figure 4.8 If someone triggers the push button, the LCD display will display “thank you”, followed by the current time.

For the third step is administrator need to do is fill the form at admin

pages to schedule the time taken of medicine for elderly. It is means that it will

record to Mysql and it will send data to Esp32 to executed

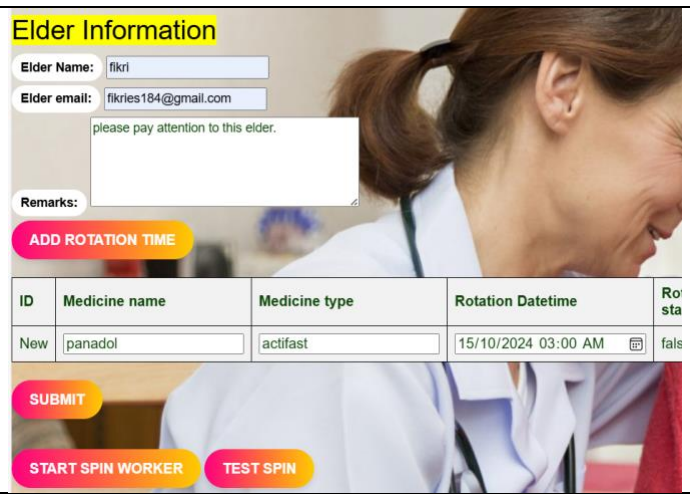
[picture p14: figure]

Figure 4.9 Before submitting the form, the administrator must fill up the elder's details in the admin pages.

Figure 4.10 After administrator submit the form, Server will request to Esp32

Figure 4.11 Administrator need to press “Start Spin Worker” at Figure 4.7 so that Web application can send data every 3 second.

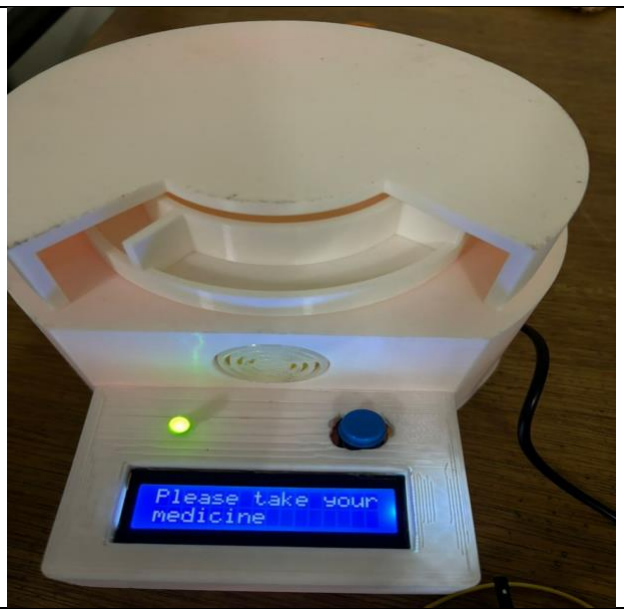
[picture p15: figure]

Figure 4.12 After ESP32 received data string from the web application, Stepper motor will rotate based on schedule and other component will work like Figure 4.7-4.8

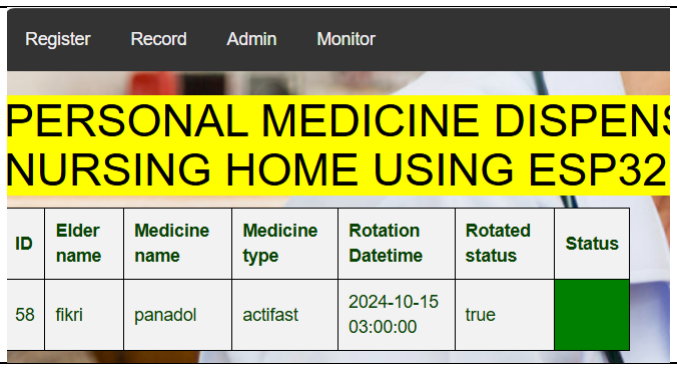
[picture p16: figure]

Figure 4.13 Administrator can check the status to see if the elder has taken the medication yet. If the status has showed Green, then means Elder has taken the medicine.

In the final stage, the administrator can access all data from the web

application and ESP32 in the MySQL database. It signifies that all of the

operations in the flowchart have been completed successfully

Figure 4.14 Table for Admin detail

Figure 4.15 Table for register

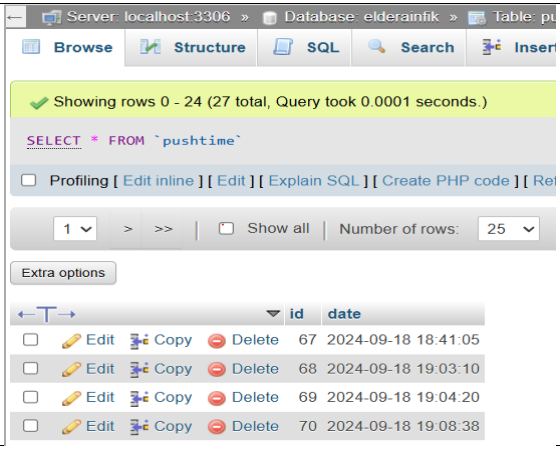
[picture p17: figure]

Figure 4.16 Table for monitoring

Figure 4.17 Notification Status Using Gmail

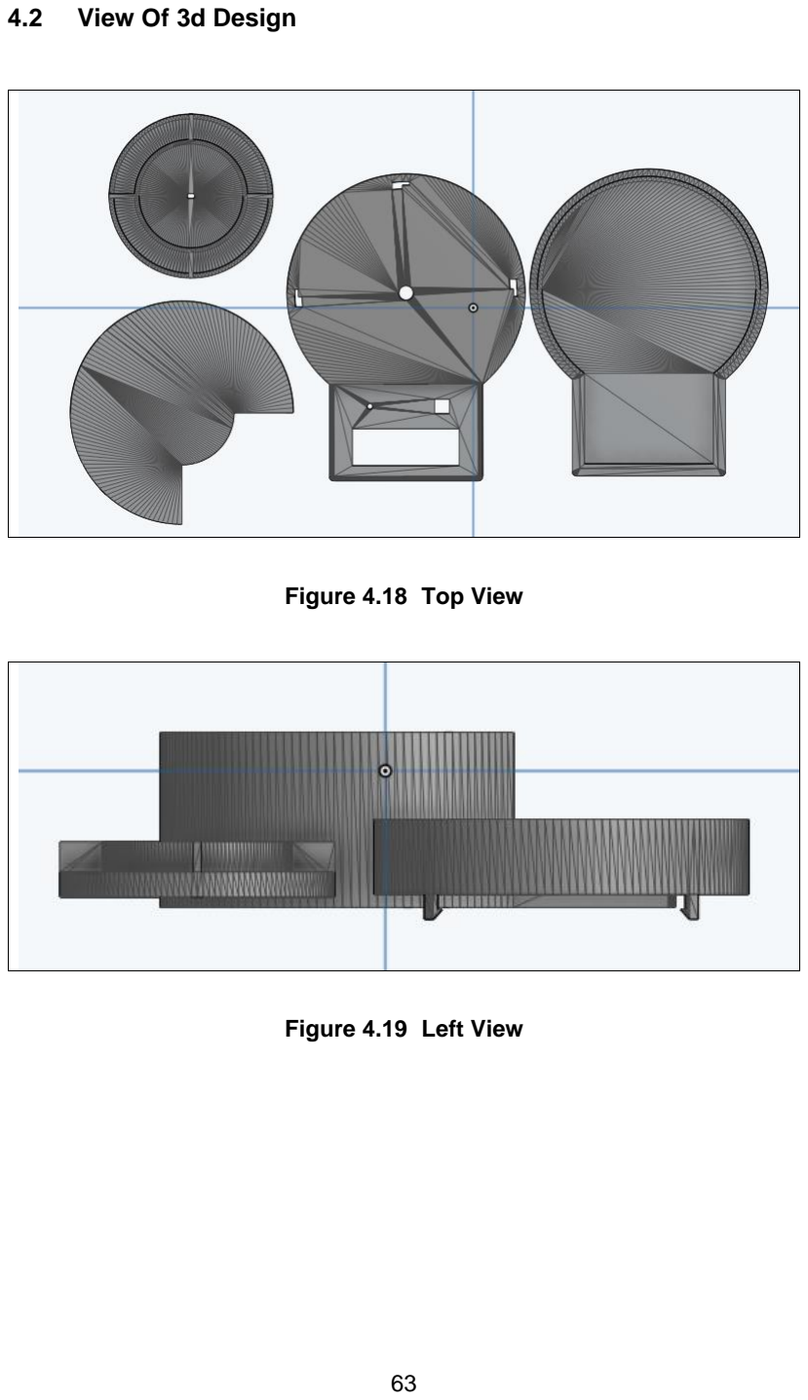
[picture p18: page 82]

### 4.2 View Of 3d Design

Figure 4.18 Top View

Figure 4.19 Left View

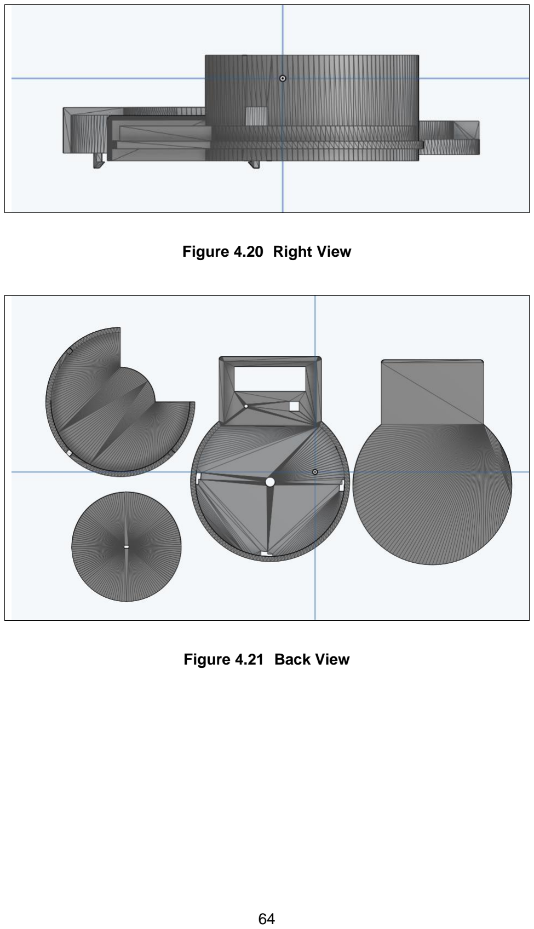
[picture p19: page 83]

Figure 4.20 Right View

Figure 4.21 Back View

### 4.3 Simulation

Figure 4.22 Simulation

### 4.4 Circuit Measurement

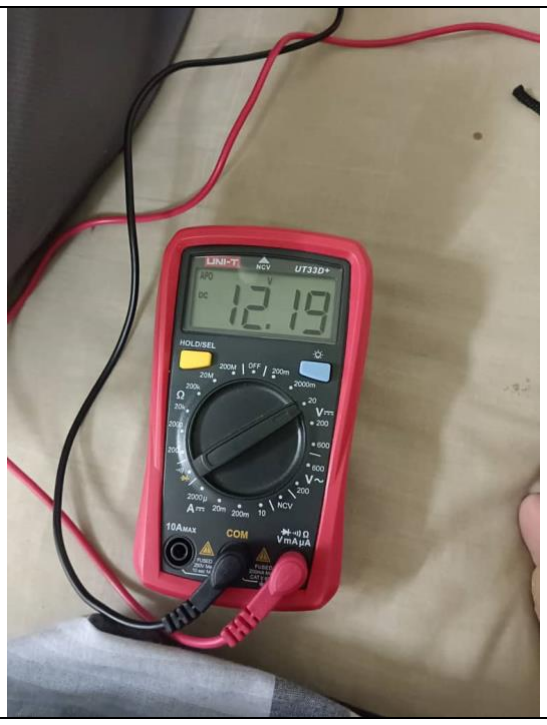
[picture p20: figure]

Figure 4.23 Voltage at
Power Jack

Figure 4.24 Volatage at
Capacitor1

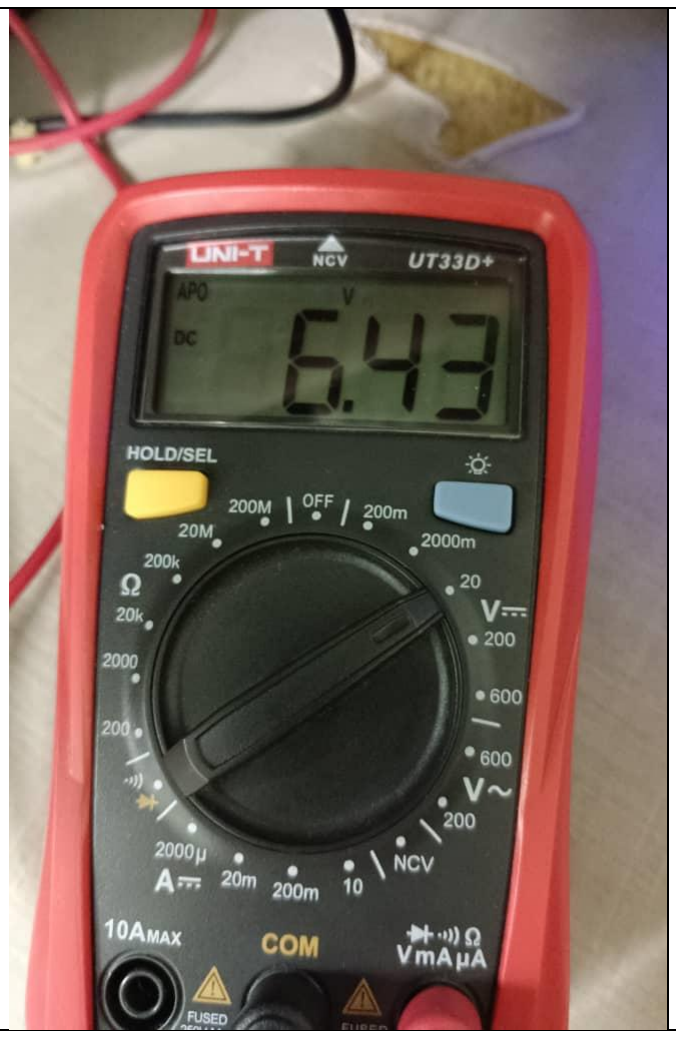
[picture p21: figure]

Figure 4.25 Voltage at
Regulator

Figure 4.26 Voltage at
Capacitor2

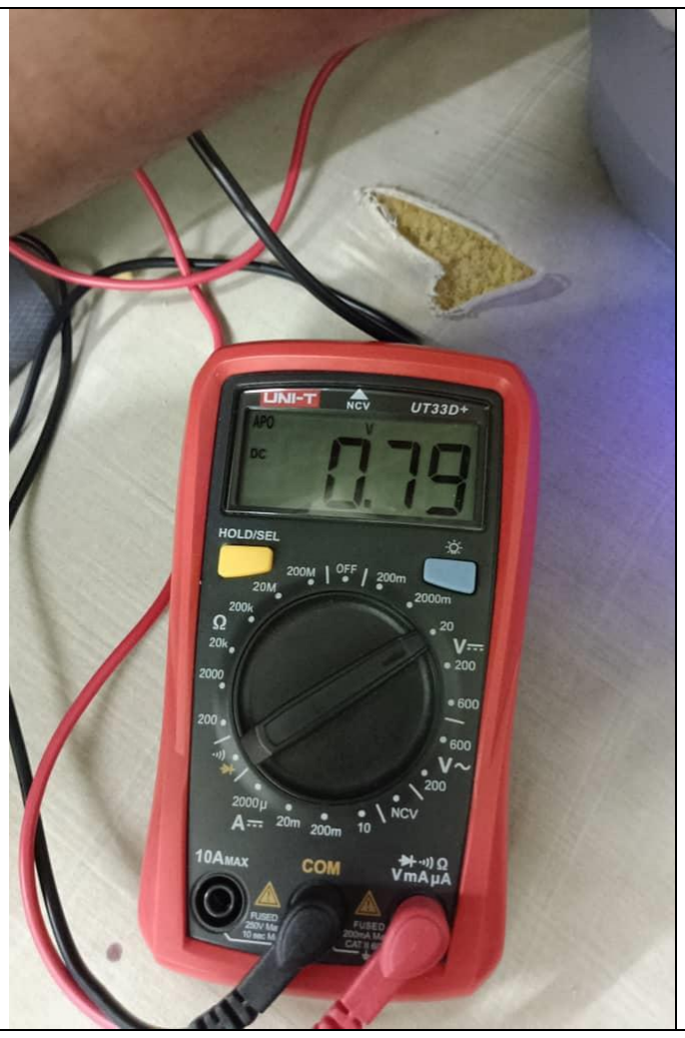
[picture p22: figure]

Figure 4.27 Voltage at at
Stepper motor

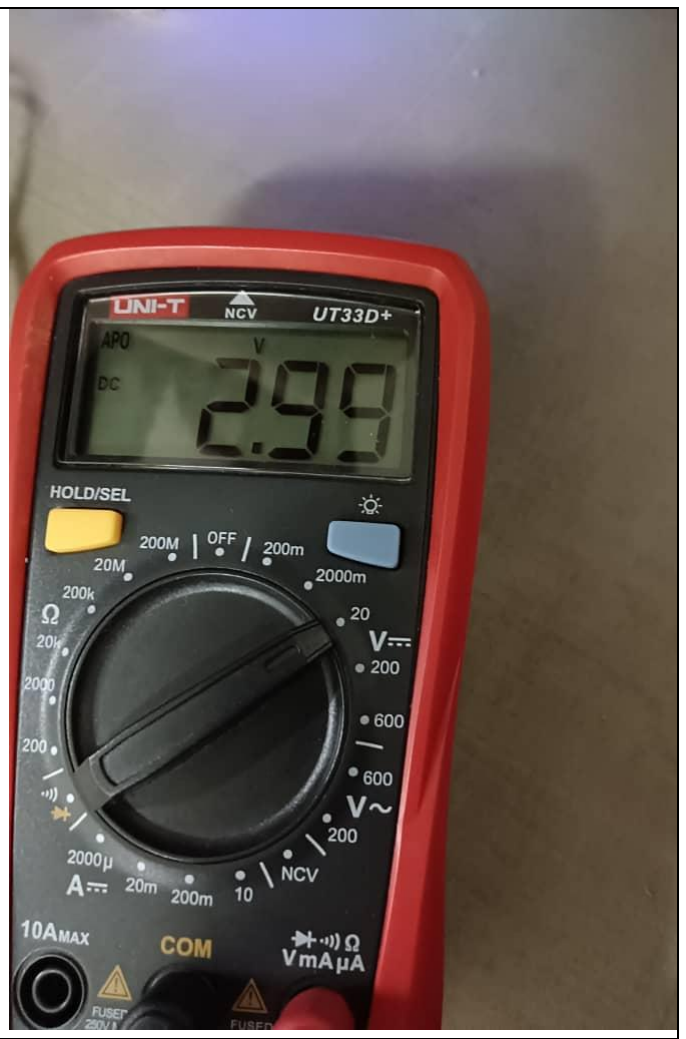
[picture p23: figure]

Figure 4.28 Voltage during rotation at
stepper motor

Figure 4.29 Voltage at Buzzer and Led during High

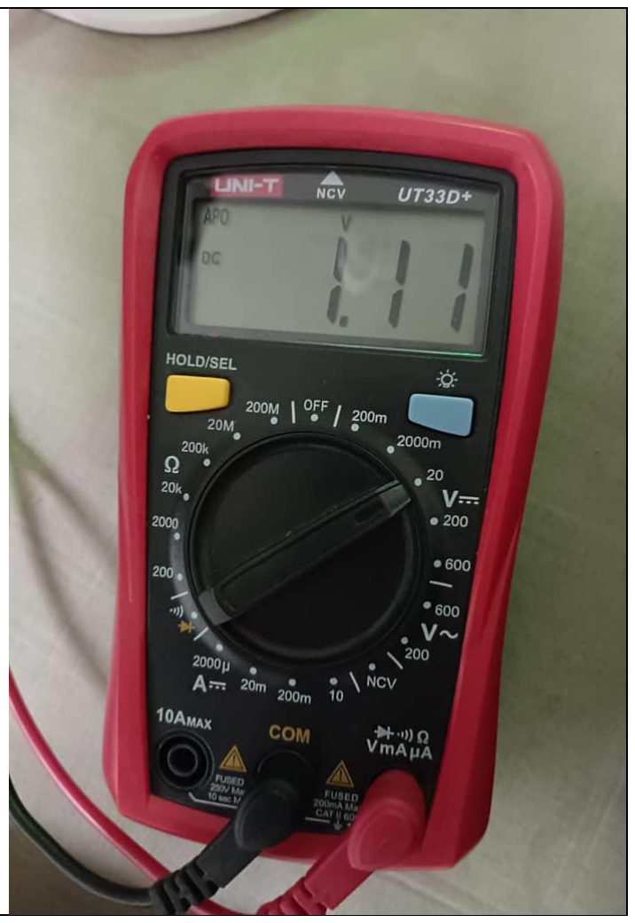
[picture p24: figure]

Figure 4.30 Voltage at Push Button During
Pressed

### 4.5 PCB Design

Figure 4.31 Back Design for PCB board

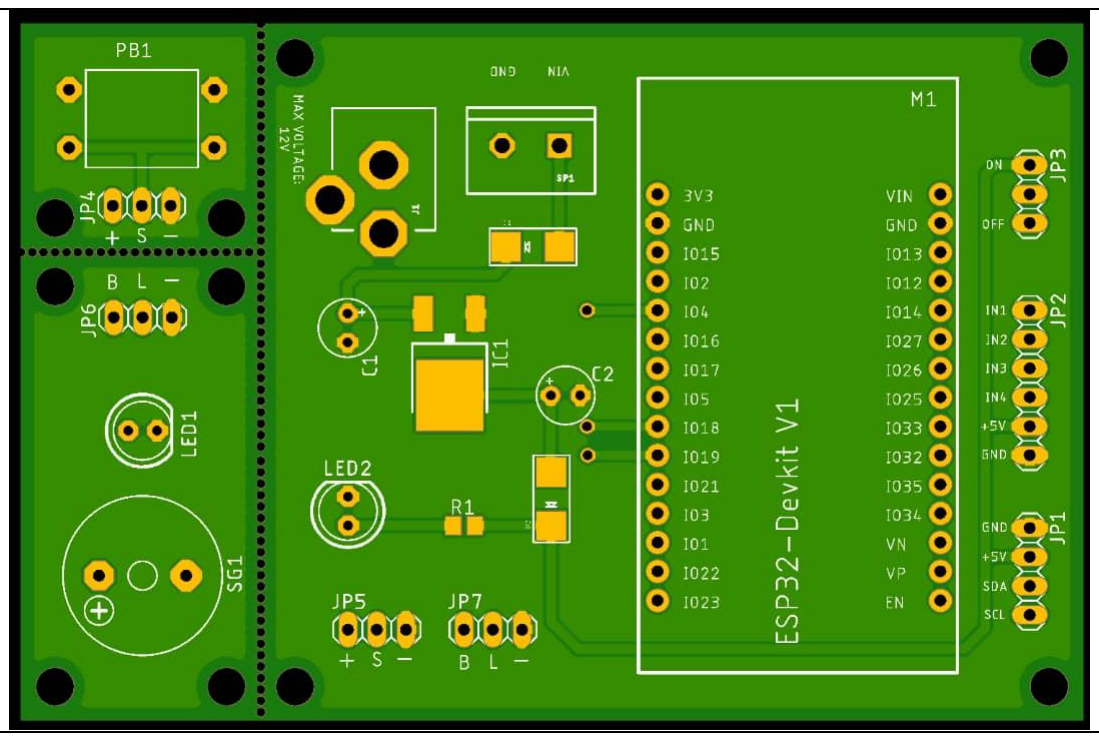
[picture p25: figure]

Figure 4.32 Top Design for PCD Board

In Figures 4.27 and Figure 4.28, the final circuit design for this project

is presented. The PCB design is crafted with a 2-layer circuit, featuring

connections on both the top and bottom layers. This approach facilitates

seamless circuit connections across all boards and provides enhanced

visibility of space and traces, enabling easier identification of any potential

defects in the PCB design. Additionally, variations in size are incorporated for

power supply, ground, and other connections. Specifically, the power supply

and ground wired connections are sized differently to ensure that if there is an

overpower situation, the PCB design circuit remains undamaged, with only the

individual component at risk.

## CHAPTER 5

5CONCLUSION AND RECOMMENDATIONS

This chapter aims to evaluate the effectiveness and reliability of the

medicine dispenser system based on the data collected during the testing

phase. By examining the performance of key components, such as the

medicine dispensing mechanism, notification system using Gmail, and web

application integration, this chapter assesses the system’s functionality and

identifies any limitations. The insights gathered will provide a foundation for

evaluating the project’s objectives, the impact of real-time notifications on

elderly care in nursing homes, and potential improvements for future iterations.

Conclusion

### 5.1 Conclusion

In summary, the objectives of this project, which include develop a

smart pillbox with automated dispenser integrated with web application, notify

elderly in adhering (Buzzer and Led) to take prescription timely per schedule,

have been successfully achieved. This project addresses a critical issue

highlighted in Chapter 1, primarily affecting elder, wherein nursing home often

face the challenge that proper management medicine and also lack of

database. This lack of awareness poses a risk, potentially leading to

misprescription can harm the elderly in nursing home.

The medicine dispenser also has a lot of benefits. It has an easy-to-use

push button built in and notification to make sure that elder press the button to

make sure data is send to MYSQL database and Alert the caregiver to ensure

they check whether the elderly person has taken their medication or not.

Lastly, the design of the medicine dispenser improves its time

management and capability, enabling it to dispense the medicine base on

schedule that administrator set it from web-application With these

characteristics, the medicine dispenser with notification for elderly care in

nursing home solves common nursing home concerns and provides a safe

and time manage for dispense medicine based on schedule.

### 5.2 Future Developments

To enhance the usability and effectiveness of the medicine dispenser

for elderly nursing home residents, I recommend integrating an emergency

push button for nurses. This feature allows elders to seek help immediately if

they encounter difficulties with their medication, ensuring a safer environment.

Notifications can be sent directly to caregivers for swift action, potentially

reducing health risks.

Furthermore, designing multiple sub-containers for medication ensures

inclusivity and flexibility. These sub-containers allow tailored solutions for

various residents and their unique medical needs. Adopting such features will

significantly improve the system’s functionality and ensure that it is user-

friendly and reliable for all stakeholders in a nursing home setting.

REFERENCES

V. Dhukaram and C. Baber, "Elderly Cardiac Patients' Medication

Management: Patient Day-to-Day Needs and Review of Medication

Management System," 2013 IEEE International Conference on Healthcare

Informatics, pp. 107-114, 2013.

S. L. Gray, J. E.Mahoney, and D. K.Blough, “Medication Adherence in Elderly

Patients Receiving Home Health Services following Hospital Discharge.”

Annals of Pharmacotherapy, 35(5), pp. 539-545, 2001.

C. F rca , I. Ciocan, N. Palaghi and R. Fize an, "Weekly electronic pills

dispenser with circular containers," 2015 IEEE 21st International Symposium

for Design and Technology in Electronic Packaging (SIITME), pp. 125-129,

2015.

N. B. Othman and O. P. Ek, "Pill dispenser with alarm via smart phone

notification," 2016 IEEE 5th Global Conference on Consumer Electronics, pp.

1-2, 2016.

MeDuino: Smart Automatic Medicine Reminder. (n.d.). Projecthub.arduino.cc.

https://projecthub.arduino.cc/ashraf_minhaj/meduino-smart-automatic-

medicine-reminder-12ffd4

AUTOMATIC | PILL | DISPENSER. | (n.d.). | Instructables.

https://www.instructables.com/AUTOMATIC-PILL-DISPENSER/

Fikries. | (2024). GitHub | - | Fikries/Smart-Medcare-Dispenser. | GitHub.

https://github.com/Fikries/Smart-Medcare-Dispenser

APPENDIX A
ARDUINO IDE CODING

#include <WiFi.h>

#include "time.h"

#include "sntp.h"

#include <WiFiClient.h>

#include <WebServer.h>

#include <Stepper.h>

#include <HTTPClient.h>

#include <Wire.h>

#include <LiquidCrystal_I2C.h>

const char* ssid = "t";

const char* password = "fikri280012";

const char* ntpServer1 = "my.pool.ntp.org";

const char* ntpServer2 = "asia.pool.ntp.org";

const long gmtOffset_sec = 28800;

const int daylightOffset_sec = 0;

const int lcdColumns = 16;

const int lcdRows = 2;

LiquidCrystal_I2C lcd(0x27, lcdColumns, lcdRows);

bool medicineMessageDisplayed = false;

unsigned long stepperRotateTime = 0;

const unsigned long buttonTimeout = 60000; // 1 minute timeout

bool timeoutWarningShown = false;

bool stepperRotated = false;

void printLocalTime() {

if (medicineMessageDisplayed) {

return; // Do not update time if medicine message is displayed

}

struct tm timeinfo;

if (!getLocalTime(&timeinfo)) {

Serial.println("No time available (yet)");

return;

}

lcd.clear();

lcd.setCursor(0, 0);

lcd.print("Date: ");

lcd.print(timeinfo.tm_year + 1900);

lcd.print("-");

if (timeinfo.tm_mon < 9) {

lcd.print("0");

}

lcd.print(timeinfo.tm_mon + 1);

lcd.print("-");

if (timeinfo.tm_mday < 10) {

lcd.print("0");

}

lcd.print(timeinfo.tm_mday);

lcd.setCursor(0, 1);

lcd.print("Time: ");

if (timeinfo.tm_hour < 10) {

lcd.print("0");

}

lcd.print(timeinfo.tm_hour);

lcd.print(":");

if (timeinfo.tm_min < 10) {

lcd.print("0");

}

lcd.print(timeinfo.tm_min);

lcd.print(":");

if (timeinfo.tm_sec < 10) {

lcd.print("0");

}

lcd.print(timeinfo.tm_sec);

}

void timeavailable(struct timeval* t) {

Serial.println("Got time adjustment from NTP!");

printLocalTime();

}

#define IN1 14

#define IN2 27

#define IN3 26

#define IN4 25

const int stepsPerRevolution = 2048;

const int ledPin = 19;

const int buzzerPin = 18;

const int buttonPin = 4;

WebServer server(80); // Create a web server listening on port 80

Stepper myStepper(stepsPerRevolution, IN1, IN3, IN2, IN4);

int currentState; // the current reading from the input pin

int previousState; // the previous reading from the input pin

void setup() {

Serial.begin(115200);

pinMode(ledPin, OUTPUT);

pinMode(buzzerPin, OUTPUT);

pinMode(buttonPin, INPUT_PULLUP);

lcd.init();

lcd.backlight();

sntp_set_time_sync_notification_cb(timeavailable);

configTime(gmtOffset_sec, daylightOffset_sec, ntpServer1, ntpServer2);

Serial.printf("Connecting to %s ", ssid);

WiFi.begin(ssid, password);

while (WiFi.status() != WL_CONNECTED) {

delay(500);

Serial.print(".");

}

Serial.println(" CONNECTED");

myStepper.setSpeed(5);

Serial.println("WiFi connected.");

Serial.println("IP address: ");

Serial.println(WiFi.localIP());

// Define server routes

server.enableCORS();

server.enableCrossOrigin();

server.on("/index.html", HTTP_GET, handleRequest);

server.begin();

Serial.println("HTTP server started.");

previousState = digitalRead(buttonPin);

}

void loop() {

server.handleClient();

int buttonState = digitalRead(buttonPin);

// Check for button press to reset LCD

if (buttonState == LOW && previousState == HIGH) {

digitalWrite(ledPin, LOW);

digitalWrite(buzzerPin, LOW);

sendButtonRequest();

if (medicineMessageDisplayed) {

// Reset states after button press

medicineMessageDisplayed = false;

timeoutWarningShown = false; // Reset timeout warning

stepperRotated = false; // Reset stepper rotated flag

lcd.clear();

lcd.setCursor(0, 0);

lcd.print("THANK YOU");

delay(5000); // Display "THANK YOU" for 5 seconds

medicineMessageDisplayed = false; // Ensure the message is marked off

}

printLocalTime(); // Return to displaying the current time

}

previousState = buttonState;

if (!medicineMessageDisplayed) {

delay(1000);

printLocalTime();

}

}

void handleRequest() {

server.send(200, "text/plain", "Executed");

rotateStepperAndShowMessage();

}

rgb.setPixelColor(0, 0, 0, 0); // off RGB light

rgb.show();

delay (500);

}

if (distance_cm < 10){

rgb.setPixelColor(0, 255, 0, 0); // show color Red

digitalWrite(RELAY_PIN, HIGH);

rgb.show();

delay (2000);

rgb.setPixelColor(0, 0, 0, 0); // off RGB light

rgb.show();

delay (500);

}

digitalWrite(RELAY_PIN, LOW);

}

void rotateStepperAndShowMessage() {

// Move the stepper motor 90 degrees

int stepsToRotate = (stepsPerRevolution * 90) / 360;

myStepper.step(stepsToRotate);

// Turn on LED and buzzer for 10 seconds

digitalWrite(ledPin, HIGH);

digitalWrite(buzzerPin, HIGH);

// Display medicine message on LCD

lcd.clear();

lcd.setCursor(0, 0);

lcd.print("Please take your");

lcd.setCursor(0, 1);

lcd.print("medicine");

medicineMessageDisplayed = true;

// Update timing for timeout warning

stepperRotateTime = millis();

stepperRotated = true; // Set flag indicating stepper has rotated

}

void sendButtonRequest() {

if (WiFi.status() == WL_CONNECTED) {

HTTPClient http;

// Your target URL for the GET request

http.begin("https://amirulasri.com/fikriainfyp/submitbutton.php");

int httpCode = http.GET();

if (httpCode > 0) {

String payload = http.getString();

Serial.println(httpCode);

Serial.println(payload);

} else {

Serial.println("Error on HTTP request");

}

http.end();

}

}

83

APPENDIX B
GANTT CHART

DIPLOMA IN ELECTRONIC ENGINEERING (DATA TRANSMISSION & NETWORK) 2024 MJII

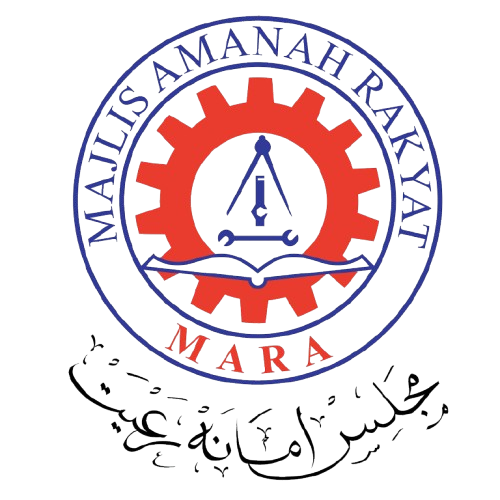
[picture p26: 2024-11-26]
asset/mara.png

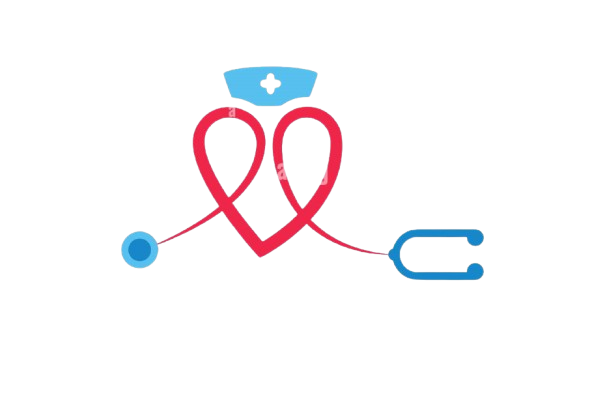
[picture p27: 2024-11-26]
asset/nursing.png

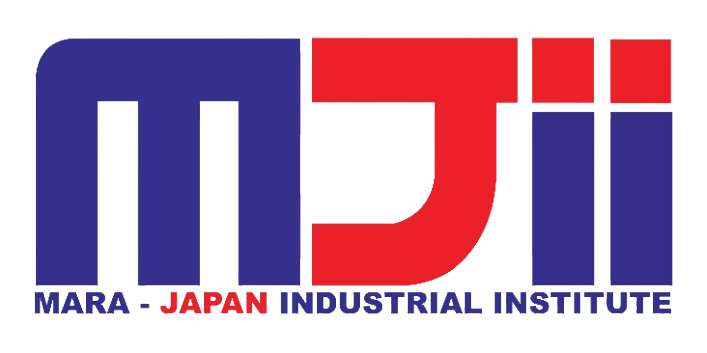
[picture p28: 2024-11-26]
asset/mjii.png

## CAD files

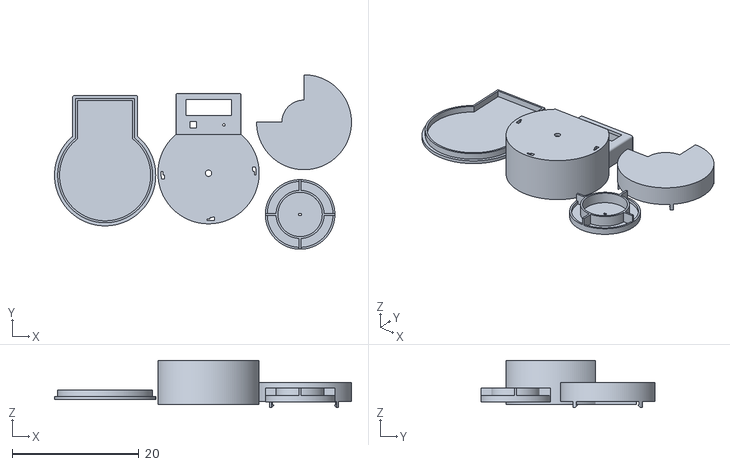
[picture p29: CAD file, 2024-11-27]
Assembly 1.stl
46.9 x 27.6 x 7.48
